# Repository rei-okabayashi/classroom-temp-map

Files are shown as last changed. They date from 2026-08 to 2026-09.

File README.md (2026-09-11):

# 教室の温度ムラ「見える化」

訓練校のチーム制作（自主活動・授業時間外）として、教室内の温度ムラをセンサーで可視化するプロジェクトです。
ESP32（無線通信ができる小型マイコンです。マイコンとは、プログラムで動く小さなコンピューターのことです）を使ったノード（教室に置く測定係の小さなコンピューターです。ESP32＋温湿度センサーのセットで、n1〜n4の4台があります）が、教室内の複数地点で温湿度を測ります。教壇のM5Stack（画面つきの小型マイコンです。教壇に置いて受信データを表示・記録します）に無線で集約したうえで、画面表示とSD記録を経てデータ分析まで行います。
メンバーは今回が初めてのチーム開発で、実際に手を動かして完成させる経験を積み、就活で語れる実績につなげることを目的にしています。
2026年8月17日のDay 0でチーム開発を開始し、9月4日に完成デモ、**9月11日（金）15:10から校内発表**を行います（普段の教室で、授業終了の5分後にそのまま始めます）。

## わかったこと（実測の結果）

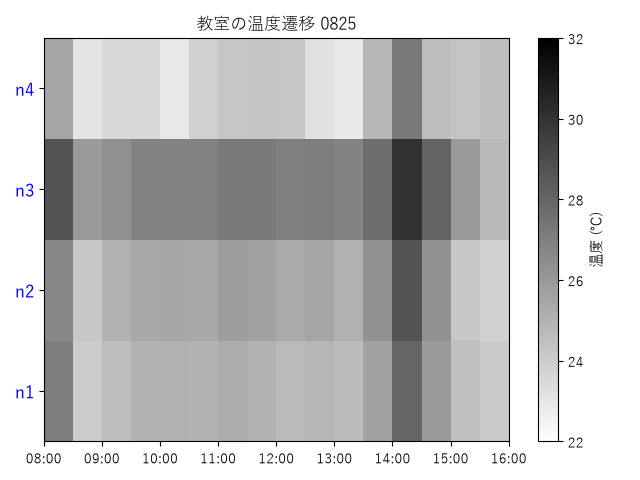
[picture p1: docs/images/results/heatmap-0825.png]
8/25の教室内温度のヒートマップ。横軸が時刻（8:00〜16:00）、縦軸が4つの設置地点、濃いほど高温


*8/25の実測例。縦軸のn1〜n4は下の「ノードと設置場所」の対応表のとおりで、n3が教卓付近です。発表当日に配ったA4資料に合わせて白黒に変換してあります（原図は分析担当がPythonのmatplotlibで作成）。*

2026年8月24日16:08〜8月28日15:47のあいだ、教室内の4地点で30秒ごとに測り続けた結果です。

- **同じ瞬間の最大の差は 4.3℃**（8/25 10:21。教卓 27.0℃ ↔ 廊下側前2 22.7℃）
- **4地点の温度差の中央値は 1.9℃**。9〜14時は約2℃、15〜16時は1.3〜1.4℃に縮みました
- 4台がそろって比較できた授業時間のうち、**約99%で教卓のほうが廊下側より暖かい**という、同じ向きの差が出ました
- エアコンを止めた休日に4台の値を突き合わせたところ、地点ごとの平均の幅は **0.18℃** でした。見たい差の10分の1以下だったので、**補正（校正）はかけず、生の値のまま**分析しています

「席によって暑い・寒いが違う」という体感が、数字として確かめられた形です。
集計とグラフの手順は [analysis/README.md](analysis/README.md)、スクリプトは [analysis/](analysis/) にあります。

## システム構成

図中のSHT31は、温度と湿度を測るセンサー部品の型番です。

```mermaid
flowchart LR
    n1["n1<br/>ESP32 + SHT31"]
    n2["n2<br/>ESP32 + SHT31"]
    n3["n3<br/>ESP32 + SHT31"]
    n4["n4<br/>ESP32 + SHT31"]
    gw["M5Stack Basic<br/>（教壇付近に常設予定）"]
    disp["画面表示 ＋ SD記録<br/>（LOG.CSV）"]
    analysis["SQLite / Python<br/>で分析"]
    demo["校内発表"]

    n1 -->|ESP-NOW 30秒ごと| gw
    n2 -->|ESP-NOW 30秒ごと| gw
    n3 -->|ESP-NOW 30秒ごと| gw
    n4 -->|ESP-NOW 30秒ごと| gw
    gw --> disp
    disp --> analysis
    analysis --> demo
```

## リポジトリ構成

リポジトリ（プロジェクト一式の保管場所です。フォルダごと、変更履歴つきで置いてあります）の全体は次のとおりです。

```
classroom-temp-map/
├── firmware/
│   ├── node-template/      # ノード側の雛形（コピーして使う。書き換えるのはconfig.hとreadSensor()のみ）
│   │   ├── node-template.ino
│   │   └── config.h
│   ├── nodes/               # 各メンバーが node-template をコピーして育てた実物（4台とも稼働ずみ）
│   │   ├── n1/n1.ino         # 【rei-okabayashi】
│   │   ├── n2/n2.ino         # 【M27Kyara】
│   │   ├── n3/n3.ino         # 【fukura-suzme】
│   │   └── n4/n4.ino         # 【mozu-sabo】
│   └── gateway/              # 集約側（M5Stack Basic）。表示とSD記録を担当
│       ├── gateway.ino
│       └── config.h
├── hardware/
│   └── case/                 # ノードを収める3Dプリント筐体（全高58.5mmの3段積み）
│       ├── node_case_v3.py   # 設計の元データ（build123d。寸法を変えて出力し直せます）
│       └── stl/              # 印刷用STL（shell_n1〜n4 ＋ box ＋ lid）
├── docs/
│   ├── data-contract.md      # ノード⇄集約の通信・データ形式の約束事
│   ├── setup-windows.md      # 開発環境セットアップ・ビルド・書き込み手順（Windows）
│   ├── first-boot-check.md   # 初回起動チェックとデータ回収の手順
│   ├── final-week.md         # 完成デモからの仕上げの段取り
│   └── presentation-outline.md  # 校内発表の構成案と想定問答
├── analysis/
│   ├── log_to_sqlite.py      # LOG.CSV→SQLite取り込み＋基本集計（標準ライブラリのみ）
│   ├── heatmap_temp.py       # 時間帯×地点のヒートマップ（pandas + matplotlib）
│   ├── data_analysispra.py   # 1地点ぶんの折れ線グラフ
│   ├── data_multibar.py      # 4地点をまとめた折れ線グラフ
│   ├── README.md             # 分析担当の作業手順
│   └── sample/LOG.CSV        # 動作確認用ダミーデータ
├── .github/
│   ├── ISSUE_TEMPLATE/task.md
│   └── pull_request_template.md
└── .gitignore
```

## 資料の読みかた

知りたいところだけ開けば大丈夫です。全部読む必要はありません。

| 知りたいこと | 読むもの |
|---|---|
| ノードと集約の通信・データ形式の取り決め | [docs/data-contract.md](docs/data-contract.md) |
| 開発環境の作り方・ビルド・書き込み（Windows） | [docs/setup-windows.md](docs/setup-windows.md) |
| 設置した機材の初回チェックとデータ回収 | [docs/first-boot-check.md](docs/first-boot-check.md) |
| 集計とグラフの手順 | [analysis/README.md](analysis/README.md) |
| 発表の構成と想定問答 | [docs/presentation-outline.md](docs/presentation-outline.md) |
| 完成デモから発表までの段取り | [docs/final-week.md](docs/final-week.md) |
| ノードのケース（3Dプリント） | [hardware/case/README.md](hardware/case/README.md) |
| 各ノードのコードの育て方 | [firmware/nodes/README.md](firmware/nodes/README.md) |

制作期間中に使っていた進め方の資料（Day 0の進行台本、放課後の時間割、Git素振り、初期タスク台帳、タスクカードの見かた、拡張バックログ、削る順序など）は、
**制作の終了にあわせて整理しました**。役目が終わった足場なので消しましたが、変更履歴には残っているのでいつでも取り出せます。
やったことの記録としては、Issue（#7〜#29 ほか）とPRの履歴のほうが実物に近いです。

## データ契約

ノードと、集約役のM5Stack（ゲートウェイとも呼びます。4台のノードからデータを受け取ってまとめる係です）の間の約束事は [docs/data-contract.md](docs/data-contract.md) に定義しています。要点だけ書くと：

- 30秒に1回、ESP-NOW（WiFiルーターなしでESP32どうしが直接データを飛ばせる無線のしくみです）を使って送信します。ユニキャスト（その場の全員に向かって叫ぶのではなく、宛先を1台決めて送る方式です）で送り、チャンネル（無線の通り道の番号です。トランシーバーの「チャンネルを合わせる」と同じ考え方です）は1に固定、暗号化はなしです。データの形式はJSON（ジェイソン。「項目名:値」をカンマで並べる、機械が読み間違えないためのデータの書き方です）を使います。送達確認がNGの場合は、1秒後に1回だけ再送します。
- ペイロード（1回の送信で運ぶデータの中身です）例：`{"v":1,"id":"n1","seq":123,"t":26.4,"h":55.2}`（読み下すと「契約の版は1。私はノードn1。起動してから123回目の送信。気温26.4℃、湿度55.2%」という内容です。読み取り失敗時は`t`/`h`の代わりに`"err":"sensor"`を送ります）。
- 集約側はSDカードの `LOG.CSV`（CSV＝カンマ区切りの表形式ファイルです。Excelやスプレッドシートでそのまま開けます）に、生値（生データ。センサーが返した値を補正せずそのまま記録したものです）のまま1行ごとフラッシュ（flush。書き込み待ちのデータをその場でSDカードに確定させることです。突然電源が切れても消えないようにします）で記録します（列：`recv_time,clock,node_id,seq,temp_c,hum_pct,status`）。追加の校正（キャリブレーション＝基準になる温度計と並べて測り、センサーごとのズレを調べること）は実施しません。SHT31が出荷時に校正済みのセンサーであるためです（理由は docs/presentation-outline.md の想定問答3）。画面表示も記録も分析も生値で統一していて、補正はどこにも掛けていません。

## チームの決めごと

ここにある決めごとは企画者が用意した叩き台です。Day 0で確認して確定し、9/4のKPT（ふりかえりの型です。Keep＝続けること・Problem＝困ったこと・Try＝次に試すこと、の3つで振り返ります）で見直します。

### Git運用

GitHub（書いたプログラムの変更履歴を記録・共有できるWebサービスです）上でチーム開発を進めます。

- Git運用の流れは「ブランチを切る → PRを出す → 企画者レビュー → マージ」です。ブランチ（feature branch）とは、本体（main）に影響を与えずに作業するための、枝分かれした作業用コピーです。PR（Pull Request）とは、「この変更を本体に取り込んでください」という提案で、チームの誰かが確認してから取り込みます。マージとは、提案された変更を本体に取り込むことです。
- `main` への直接push（プッシュ：自分のPCでの記録をGitHub側に送って反映することです）は禁止です
- ツールはgitコマンドとVSCodeを使います（GitHub Desktopは使いません）

### AIルール

1. 共通テンプレートを使います（各自のノードは `firmware/node-template/` をコピーして始めます）
2. データ形式の契約を守ります（`docs/data-contract.md` のフィールドを勝手に増やしません。変えたいときはチームで合意してから版を上げます）
3. 説明できないコードはマージしません（AIに書かせた部分も含めて、PRの説明欄に自分の言葉で書きます）
4. AI利用箇所を記録します（日々の記録はPR説明欄に書き、発表とりまとめ担当が「AI活用の記録」節の表に転記します。企画者は内容をレビューで確認します）

使いどころの目安は次のとおりです。エラーメッセージの解読・コードの意味の説明・文章や表の下書きには積極的に使ってOKです。コードを丸ごと生成させて、自分で説明できないまま持ち込むのはNGです（ルール3のとおり）。

### 週次リズム

- 月曜: 週次キックオフ15分（今週の各自のタスクカード＝Issue（やることを1件ずつカードにしたものです）を確認します）
- 毎日: Discordに2行報告します（きょうやった／困ってる）。書くだけでOKです。返信は必須にしません
- 金曜: 中間デモ（8/21・8/28）です。進捗の判定はこの場でだけ行います。9/4(金)は完成デモ＋ふりかえり（KPT）です
- 詰まったら24時間以内に申告してください→企画者と30分ペア作業します。遅れは責めません（タスクの切り方が悪かったとみなして分解し直します）
- 時間の上限は週5〜8hです。上限は超えません（作業量は役割ごとに波がありますが、上限と見える化で揃えます）
- 完成が危うくなったら、あらかじめ決めた順に規模を削ります（削る順序は、着手前に決めて文書化しておきました）

## 役割分担表

| 役割 | 担当 | 補足 |
|---|---|---|
| 企画・全体とりまとめ | 【rei-okabayashi】 | テンプレート整備・レビューを行います。**他メンバーの**ノード実装と発表スライド本体には手を出しません（自分のノード1台は担当します） |
| ノード担当（n1〜n4） | 【rei-okabayashi】【M27Kyara】【fukura-suzme】【mozu-sabo】 | 企画者を含めて1人1台です。センサー実装・設置・動作確認を行います |
| 集約表示オーナー | 【fukura-suzme】 | M5Stack側の画面表示・SD記録を担当します。担当者はノード1台と兼務します（4名全員がノード1台ずつ担当するためです）。M5Stackは企画者の個人所有物のため、譲渡の対象外です |
| データ分析 | 【mozu-sabo】 | 訓練校で学んだSQLite（ファイル1つで使える小さなデータベースです）を活用します |
| 発表とりまとめ | 【M27Kyara】 | 校内発表用スライドを作成します |
| 筐体 | 【rei-okabayashi】 | ノードのケース化などを行います。基本は企画者が担当しますが、やってみたい人がいればその人が正式な担当になります（他の役割と同格です） |

※ 1人が複数の役割を兼ねることがあります。担当欄はGitHubのユーザー名で記入します（公開リポジトリのため本名は書きません）。

## ノードと設置場所

| ノードID | 設置場所 | 担当 |
|---|---|---|
| n1 | 窓側（後ろ寄り） | 【rei-okabayashi】 |
| n2 | 窓側（前寄り） | 【M27Kyara】 |
| n3 | 教卓付近 | 【fukura-suzme】 |
| n4 | 廊下側（前寄り） | 【mozu-sabo】 |

設置場所は「窓側」「廊下側」「教卓付近」のような役割ベースの言い方にしています。

## 機材と費用

### 機材一覧

使用機材の一覧です。担当作業で「この部品の特性（ピン配置・仕様・使い方）を知りたい」となったら、**資料列のリンク**を開いてください。アイテムごとに、いちばん役立つ資料を1つだけ厳選して貼ってあります。参考単価は秋月電子への発注時（2026-08-01）のものです。

| 機材 | 数量 | 参考単価 | このプロジェクトでの役割 | 資料（各1つ厳選） |
|---|---|---|---|---|
| ESP32-DevKitC-32E ESP32-WROOM-32E開発ボード 4MB（秋月 115673） | 4（発注3＋追加1） | ¥1,800 | ノードn1〜n4の本体です（1人1台）。PCからUSBで書き込み、ESP-NOWで測定値を送信します | [ESP32-WROOM-32Eデータシート（PDF・英語）](https://akizukidenshi.com/goodsaffix/esp32-wroom-32e_esp32-wroom-32ue_datasheet_en.pdf) |
| SHT31使用 高精度温湿度センサーモジュールキット（秋月 112125） | 4 | ¥950 | 温湿度の測定部です。I2C（少ない配線でマイコンと部品がやり取りする通信方式です）でESP32につなぎます。配線は3V3・GND・SDA(21)・SCL(22)の4本だけです | [組立・使用説明書（PDF・日本語）](https://akizukidenshi.com/goodsaffix/AE-SHT3x_manu_v1.0.pdf) |
| USBケーブル USB2.0 Aオス-マイクロBオス 1.5m（秋月 107607） | 4 | ¥170 | ノードの書き込み・給電用です（DevKitCの差し込み口はmicro-Bです） | [商品ページ](https://akizukidenshi.com/catalog/g/g107607/) |
| スイッチングACアダプター Type-Aメス 5V2A 横出し（秋月 114934） | 5 | ¥580 | 設置後の常時給電用です（ノード4台＋M5Stack1台分）。上のUSBケーブルをこれに挿してコンセントから電源をとります | [商品ページ](https://akizukidenshi.com/catalog/g/g114934/) |
| コネクター付ケーブル 20cm 40P メスメス（秋月 115868） | 1 | ¥200 | ESP32とSHT31をつなぐ配線材です。40本つながったリボン状なので、1台あたり4本ずつ裂いて使います | [商品ページ](https://akizukidenshi.com/catalog/g/g115868/) |
| USBケーブル USB2.0 TypeAオス⇔TypeCオス 1.5m（秋月 113563） | 1 | ¥130 | M5Stackの書き込み・給電用です（Basicの差し込み口はUSB-Cです） | [商品ページ](https://akizukidenshi.com/catalog/g/g113563/) |
| M5Stack Basic（初期型） | 1 | —（企画者私物） | 集約ゲートウェイです。4台のノードからESP-NOWで受信し、画面表示とSDカードへの記録を行います | [公式ドキュメント（日本語）](https://docs.m5stack.com/ja/core/basic) |
| microSDカード（LAZOS 16GB Class10） | 1 | 約¥1,000 | `LOG.CSV` の記録先です。M5StackのTFカードスロットに挿して使います | [メーカー製品ページ（L-B16MSD10-U1）](https://lazos-life.com/l-b16msd10-u1/) |

資料を読むときのヒント：

- ESP32のデータシートは英語ですが、全部読む必要はありません。ピンの役割は「Pin Definitions」、電圧・電流の上限は「Electrical Characteristics」の節だけ見れば十分です。
- SHT31の説明書は日本語で、組み立て（同梱ピンヘッダーのはんだ付け）・配線例・I2Cアドレスの切り替え・Arduinoのサンプルコードまで載っています。ノード担当が最初に読む資料はこれです（I2Cアドレスは基板そのままで `0x45`。`firmware/node-template/config.h` の設定と対応しています）。
- M5Stackのドキュメントにはバージョン違い（v2.6／v2.7）のページもありますが、今回の機体は初期型なので無印「Basic」のページを見てください。
- 秋月の商品ページはURLが `https://akizukidenshi.com/catalog/g/g<6桁コード>/` の形式です。表の「秋月 6桁」の番号からたどれます（リンク切れのときもこの形で復元できます）。

### 費用

- 秋月電子への発注分（2026-08-01）：¥13,110（上の表の単価×数量の合計。ただしESP32は3台分）
- ESP32-DevKitC-32E 追加1台（4台目）：¥1,800（参考単価）
- microSDカード（LAZOS 16GB Class10）：約¥1,000
- M5Stack Basicは企画者の私物のため、費用には計上しません
- 機材は企画者が用意します。プロジェクト終了後（9月の発表・運用終了後）に譲渡（センサーノードのみ。集約のM5Stackは対象外です）を希望するメンバーは、実費¥3,500/台です

## AI活用の記録

チームルール4（AI利用箇所をREADMEに明記します）の実践場所です。

記録は「AIを使った／使っていない」の二択にはしません。**「AIがやったこと」と「人間が判断・検証したこと」を分けて**、下の表の形式で書きます。AIに書かせること自体はルール違反ではありません——ルール3のとおり、自分の言葉で説明できることがマージの条件です。

| どこで | AIがやったこと | 人間が判断・検証したこと |
|---|---|---|
| 共通テンプレート（`firmware/node-template/`・`firmware/gateway/`） | コードの下書きを生成（Claude） | 企画者が仕様（データ契約）を決めてレビュー・修正し、コンパイルと実機の送受信で検証 |
| データ契約のドラフト（`docs/data-contract.md`） | 文書の下書きを生成（Claude） | チームで内容を確認し、企画者の承認でv1として確定 |
| このREADMEと `docs/` の各手順書 | 文章の下書きを生成（Claude） | 企画者が内容をレビュー・修正して確定 |
| #1 — ドキュメント（学校PC対応） | IDEフリーズ原因の切り分け案とプロキシ設定手順の下書き作成 | 実機での手順動作確認・最終文面の採択 |
| #2 — ドキュメント（トラブルシューティング） | clone先フォルダ既存エラーへの対処文の下書き作成 | 文面内容の確認と推敲 |
| #4 — ドキュメント（自己紹介） | 自己紹介文の自動生成 | 生成文の内容確認・必要な修正 |
| #5 — ドキュメント（Git演習手順） | 演習手順ドラフトを生成（実測値を踏まえた文面） | 実機での検証を経て採択 |
| #6 — ドキュメント（git-primer） | トラブル洗い出しと修正案（複数ファイル）の生成 | 提案の検証および採択 |
| #34 — ドキュメント（README 機材欄） | 機材説明文の作成（表・説明文案） | 内容の確認・必要箇所の修正 |
| #38 — ドキュメント（firmware/nodes README） | README 下書きの生成 | 文面の確認 |
| #40 — ドキュメント（first-boot-check） | 文章の校正・ブラッシュアップ支援 | 元原稿との差分確認・最終調整（原稿は人作成） |
| #41 — ハードウェア（3Dプリント設計） | ハードウェア説明メモ／設計アドバイスの生成 | メモの採否・設計の現物合わせ判断 |
| #43 — プログラム（折れ線グラフ） | 実装でのメソッド／関数選定に関する相談と提案 | 提案の採用箇所をコードに反映しコメントで記録 |
| #47 — CI/CD（GitHub Actions） | コンパイル自動チェック用ワークフロー案の作成・問題指摘 | CI案は未採用、スケッチ名の修正は#58で対応 |
| #50 — 設定（CODEOWNERS） | CODEOWNERS案作成・存在しないアカウント等の検出支援 | 未採用 |
| #51 — プログラム（M5Stack表示） | コンパイルエラーメッセージ解析・描画座標計算の提案 | エラー原因の特定とコード調整・動作確認 |
| #52 — ドキュメント（方針反映） | 複数ファイルの書き換え下書き（方針反映）を生成 | 人による突合せ・修正のうえ採択 |
| #53 — ドキュメント（README 役割表） | 役割表・設置場所の差替下書きを生成 | 確定値との照合・修正 |
| #54 — プログラム（折れ線グラフ一括出力） | グラフ作成プログラムの実装補助・アドバイス | 実装へ取り込み・動作確認 |
| #55 — ドキュメント（final-week） | 発表日確定に伴う資料下書き・日付更新の生成（Claude Code） | 関係者による突合せ・修正 |
| #57 — プログラム（集約画面UI） | ラベル表示・描画修正コードの全体生成（Claude Code） | 表示調整・実機確認を経てマージ済み |
| #58 — ファームウェア（スケッチ名修正） | 問題指摘・リネーム作業と説明文の生成 | 内容検証・リネーム適用 |
| #59 — ドキュメント（想定問答） | 想定問答への追記下書き生成（Claude Code） | 文意確認・採用（必要箇所を修正） |
| #60 — analysis（ヒートマップ） | 自分のコードをAIに見てもらい、書き方のわからないところやブラッシュアップしてほしい所を助けてもらい、結果的に大半をAIの提案によるコードを採用 | データベースの値と描画の突合せ・動作確認 |
| #62 — docs（想定問答・プロキシ例） | Codexで既存の集計定義と説明を照合し、数値の意味の補足およびプロキシ設定の例示化を実施 | 文言確認・採択 |
- 各メンバーが自分のノード（`firmware/nodes/n1`〜`n4`）でAIを使った場合は、そのPRの説明欄（`AIを使った箇所`）に個別に記録します。ルール3のとおり、AIに書かせた部分も自分の言葉で説明できることが前提です。
- PR説明欄の記録は、中間デモ（8/21・8/28）とKPT（9/4）のタイミングで、**発表とりまとめ担当が上の表に転記します**（企画者は内容をレビューで確認します）。記録の散逸を防ぐと同時に、発表スライドの「AIとの付き合い方」の材料づくりを兼ねます。

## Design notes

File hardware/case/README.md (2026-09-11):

# ノードケース（3Dプリント）

ESP32-DevKitC-32E（秋月 115673）と SHT31温湿度センサー（秋月 112125）を収める、
教室常設用のケースです。Bambu Lab A1 mini での印刷を前提にしています。
ここにあるのは2026年8月30日時点の版（v3）で、4台ともこのケースに入れて9月1日から教室に設置しました。

## 設計のいちばん大事な話 — センサーとESP32を縦に離す

ESP32は動作中に自分が発熱します（無線送信と電源レギュレータの熱です）。
温度センサーを同じ空間に閉じ込めると、**教室の気温ではなく「箱の中の温度」を測ってしまい、
実際より高い値**が出ます。教室の温度ムラ（実測で数℃）を測るプロジェクトでは致命的です。

そこでこのケースは、**下からセンサー室 → 空気の断絶帯 → ESP32室** の縦積みにしています。

```
        ┌──────────┐
  +48.8 │   lid    │  フタ。ESP32を上から押さえ、CPU直上に排熱の煙突とハニカム孔
        ├──────────┤
  +24.5 │   box    │  ESP32室。基板を棚に載せる。USB窓・配線穴・排気スリット
        ├──────────┤
        │  = 空気 = │  断絶帯 5.0mm（ここで熱がセンサーへ伝わりにくくなる）
        │          │
      0 │  shell   │  外殻。最下部がセンサークレードル（SHT31を上から落とし込む）
        └──────────┘   背面に磁石ポケット2個。底面の前バンドにノードIDを刻印
```

全高58.5mm、設置面は 60.3 × 33.5mm。**背面（机側）はshellからlidまで1枚の平面**なので、
磁石で壁やスチール面にぴったり付きます。

## パーツ構成

| ファイル | 中身 |
|---|---|
| `stl/node_case_v3_shell_n1.stl` 〜 `_n4.stl` | 外殻＋センサークレードル。**n1〜n4で違うのは底面の刻印だけ**です（設置後にどの子機か見分けるため） |
| `stl/node_case_v3_box.stl` | ESP32室。4台とも共通 |
| `stl/node_case_v3_lid.stl` | フタ。4台とも共通 |
| `node_case_v3.py` | 設計の元データ（後述） |

1台分 ＝ shell 1個 ＋ box 1個 ＋ lid 1個。4台なら shell を n1〜n4 で1個ずつ、box と lid を4個ずつ。

## 部品以外に必要なもの

- **ネオジム磁石 φ13 × 厚2.4mm × 2個／台**（ダイソーの13mmタイプを実測した寸法でポケットを作っています）。
  shell背面のポケットに押し込みます。2個の縁を25.6mm離してあるのは、磁石どうしが引き寄せ合って
  設置しづらくなるのを避けるためです。SHT31への磁気の影響は調べたうえで無しと判断しています。
- ジャンパー線（メスメス4本。3V3・GND・SDA21・SCL22）

## 印刷

1. Bambu Studio に STL をドラッグ＆ドロップ
2. フィラメント: **PLA**。
   ただし **PLA Matte は層間の強度が PLA Basic の43%しかありません**（メーカーTDSの実測値）。
   スナップのツメなど細い部分が折れやすいので、Matteを使うなら扱いを丁寧に
3. 向き: **3部品ともエクスポートされたそのままの向き**で置けば、サポートは要りません
4. 最初は1台分だけ刷って実物で確かめてから、残り3台を刷ってください

### 寸法を変えたいとき

`node_case_v3.py` の先頭にパラメータがまとまっています（壁厚 `WALL`、外形 `FOOT_X`/`FOOT_Y`、
空気断絶帯 `GAP`、磁石 `MAGNET_D`/`MAGNET_T`、USB窓 `USB_SLOT_W` など）。
値を変えて実行すればSTLが出し直されます。

このファイルは [build123d](https://github.com/gumyr/build123d)（Pythonで形状を書くCAD）で動きます。

```
pip install build123d
python node_case_v3.py
```

実行すると `node_case_v3_box.stl` / `_lid.stl` / `_shell_n1`〜`_n4.stl` が同じフォルダに出力されます。

## 組み立て

1. **SHT31のピンヘッダは基板の裏側（部品がない面）から下向きに**はんだ付けします
2. ジャンパー線4本でESP32（3V3・GND・21・22）とSHT31（+V・GND・SDA・SCL）をつなぎ、
   **先にPCにつないで動作確認**（[docs/first-boot-check.md](../../docs/first-boot-check.md) のA章）してからケースに入れます
3. **SHT31をshellのクレードルへ**：**タブ（センサー素子が載っている出っぱり）を先に差し込んでから、
   後端を落とす**順番で入れます。先端のツメが基板の浮き上がりを押さえます
4. **ESP32をboxへ**：USBコネクタを右壁（X+）の窓に合わせて、基板を棚に載せます。
   ジャンパー線は基板の下の空間を通し、配線穴から下（shell側）へ回します
5. **boxをshellに載せる**：パラペット（shell上部の立ち上がり）の内側に差し込むと、
   ビードが受け溝にはまってカチッと止まります
6. **lidをかぶせる**：短辺（X±）のスカート脚がboxの壁をつかみます。書き込み直し（BOOTボタン）のときは外します
7. **磁石を2個**、shell背面のポケットに押し込んで設置

## この設計に至るまで（初回印刷でわかったこと）

8月30日の午前にフル1セットを試し刷りし、その実物を見て午後に直しました。
直した内容は `node_case_v3.py` の冒頭コメントに全部残してあります。主なものは：

| 見つかった問題 | 直し方 |
|---|---|
| センサー基板が浮き上がる | 先端にツメ（トンネル状の押さえ）を新設。両側のナブを太くする案は、通過隙間12.7mm＜基板幅14.0mmで**挿入できなくなる**ため不採用 |
| boxとshellが固定されない | 押し込んで嵌るスナップを新設（ギャップ0.5mmを跨いで0.30mm食い込む2段ビード） |
| ESP32の熱がこもる | lidの押さえパッドを煙突にしてCPU直上を貫通、プレートにハニカム孔、box壁の排気スリットを下へ延長 |
| 磁石どうしが引き寄せ合って設置できない | 2個を離して独立したポケットに（縁間25.6mm） |
| ESP32の赤LEDが眩しい | ハニカム孔をCPU側（X-）だけに限定し、LED側は無孔の目隠しに |
| 横の出っぱりが邪魔で壁に付き切らない | 長辺（Y±）を本体と面一化。lidのY側スカートを廃止し、係合を短辺（X±）へ移設 |
| 外壁と内壁が細くて不安定 | 薄壁2枚が非接合で並んでいた箇所を、段付きキャビティで一体の2.5〜3.7mm壁に統合 |

その前段では、嵌合部だけを切り出したテスト用の小片（クーポン）を刷って、
スナップの食い込みと、この設定で形が出る最小の寸法を確かめています。

## 設置時の注意

- 直射日光の当たる場所は避ける（日射でセンサーが数℃高く出ます。窓際なら日陰側に）
- エアコンの吹き出し直下も避ける（気流の温度を測ってしまいます）
- ESP32のアンテナ（基板端の模様部分）に金属を密着させない。ケースのPLA樹脂自体は電波をほぼ通すので問題ありません

## ケースの影響について

このケースが測定値を持ち上げていないか、**ケースあり／なしを並べて比べる測定はしていません**。
4台とも同じケースに入っているので、持ち上がりがあれば4台に同じだけ乗り、
このプロジェクトが見たい「地点どうしの差」には影響しない、という整理です。
絶対値の底上げがあるかどうかは未測定です（[docs/presentation-outline.md](../../docs/presentation-outline.md) の想定問答3）。

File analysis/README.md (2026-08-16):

# analysis — 運用データの分析（データ分析担当の作業場所）

SDカードにたまった実測データを読み込んで、「いつ・どこが暑いか」を数字で出す場所です。
このプロジェクトの成果物（発表で見せるもの）は、ここから作ります。

---

## 0. 準備：Pythonを入れる（最初に1回だけ）

`log_to_sqlite.py` は **Python** というプログラムで動きます。入っていないPCでは動かないので、先に入れてください。

1. [https://www.python.org/downloads/windows/](https://www.python.org/downloads/windows/) を開き、Windows installer (64-bit) をダウンロードします。
2. ダウンロードした `.exe` を実行します。**最初の画面で「Add python.exe to PATH」のチェックを必ず入れてください**（ここを忘れると、次の手順で `python` と打っても認識されません）。
3. 「Install Now」を押します。
4. **開いていたターミナルはいったん閉じて、開き直します**（開きっぱなしの画面には設定の変更が反映されません）。
5. ターミナルで `python --version` と入力してEnterを押し、`Python 3.x.x` のように表示されれば準備完了です。

> **うまくいかないとき**
> - Microsoft Storeの画面が開いてしまう → 手順2の「Add python.exe to PATH」のチェックが入っていません。インストーラをもう一度実行して入れ直してください。
> - それでも認識されない → PCを再起動してから、もう一度 `python --version` を試してください。
> - どうしても入らない → 企画者に連絡してください。**Excelでも同じ集計はできます**（下の「Pythonが使えないとき」を参照）。

**追加のライブラリは要りません。** `log_to_sqlite.py` はPythonに最初から入っている機能だけで動きます。

---

## 1. まずはサンプルで動かしてみる（実データが無くてもできます）

実測データが集まるのは8/26以降です。それまでに、**ダミーデータで一度動かしておく**と本番で慌てません。

1. VSCodeでこのリポジトリ（`classroom-temp-map` フォルダ）を開きます。
2. メニューの `ターミナル`（Terminal）→ `新しいターミナル`（New Terminal）を開きます。
3. `analysis` フォルダへ移動します。

   ```
   cd analysis
   ```

4. サンプルデータで実行します。

   ```
   python log_to_sqlite.py sample/LOG.CSV
   ```

うまくいけば、ノード別のまとめと「時間帯 × ノードの平均気温」の表が画面に出ます。
**この表の一番右の「最大差」の列が、私たちが測ろうとしている「温度ムラ」そのものです。**

---

## 2. 本番：実測データで動かす

1. **回収したLOG.CSVを受け取ります。** 金曜のデータ回収のあと、回収した人が Discord の進捗報告チャンネルに `LOG.CSV` を添付します。それをダウンロードして、この `analysis` フォルダに置いてください（回収の手順は [docs/first-boot-check.md](../docs/first-boot-check.md) のC章）。
2. `analysis` フォルダにいることを確認して、実行します。

   ```
   python log_to_sqlite.py LOG.CSV
   ```

3. 画面に出た表を保存します。スクリーンショットでもよいですし、次のようにファイルへ書き出すこともできます。

   ```
   python log_to_sqlite.py LOG.CSV > result.txt
   ```

このコマンドは `LOG.CSV` を読み込み、SQLiteのデータベースファイル `onmura.db` を作ります（`onmura` は「温度ムラ」をローマ字にした、このプロジェクトの略称です）。

- `onmura.db`（SQLite。ファイル1つで使える小さなデータベースです。訓練校で学習済み）が作られ、ノード（教室に置く測定係の小さなコンピューターです）別サマリと「時間帯×ノードの平均気温」クロス表が表示されます
- **最大差の列が「温度ムラ」そのものです** — 発表の根拠データはここから作ります
- 訓練で習ったSQLiteの実践場所です。`sqlite3 onmura.db`（作られたデータベースを開いて、自分で集計を試すためのコマンドです）で開いて自由に集計してかまいません

時刻未設定（clock=unset）の行とセンサーエラー行は自動で除外されます（`--include-unset` で含められます）。
また、同じデータが2回記録されていた分（電波が届かず再送されたとき）も自動で1件にまとめられます。

---

## 3. どこまでやれば「できた」か

| 段階 | 中身 | 判定 |
|---|---|---|
| **最低限** | 上のクロス表と「最大差」の列＋グラフ1枚 | **これで発表に使えます** |
| 余裕があれば | 日別・曜日別の集計を足す | 拡張 |
| さらに | 設置場所ラベル（READMEのn1〜n4対応表）と結合して「窓際 vs 廊下側」で語る | 拡張 |

グラフを何で作るか（表計算ソフトか、Pythonのグラフ機能か）は、**1週目のうちに企画者と相談して決めます**。
どちらでも構いませんが、Pythonのグラフ機能（matplotlib）を使う場合は `pip install matplotlib` の追加インストールが必要になるので、早めに決めておくと安心です。

> 発表のグラフでは、`n1`〜`n4` という名前を「窓際」「廊下側」のような言い方に置き換えます（公開リポジトリなので、学校や教室が特定される表現を避けるためです）。集計をやり直す必要はなく、見出しの言い換えだけです。

---

## 4. Pythonが使えないとき（Excel・スプレッドシートで同じことをする）

`LOG.CSV` はただのCSVなので、ExcelやGoogleスプレッドシートで開いてピボットテーブルを作れば、同じクロス表が作れます。
ただし、**スクリプトが自動でやっている「除外」を手でやる必要があります。** ここを飛ばすと、気づかないまま平均がおかしくなります。

1. `clock` 列が `set` 以外（`unset`）の行を消します（停電などで時計が未設定だった間の行で、時刻が当てになりません）
2. `status` 列が `ok` 以外（`sensor_err`）の行を消します（気温が空欄の行です）
3. 同じ `node_id` で `seq` が直前の行と同じものがあれば、片方を消します（再送で二重に記録された分です）
4. `recv_time` の列を、日付・時刻として認識させます（列を選んで「セルの書式設定」から変更します）
5. ピボットテーブルで `recv_time` を右クリック →「グループ化」→ **「時」だけにチェック**を入れます

手数が多いので、Excelに切り替えると決めたときは企画者に声をかけてください。**除外まで済ませたシートを一度作って渡します。**

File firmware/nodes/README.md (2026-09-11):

# firmware/nodes/ — 各自のノードのコード置き場

このフォルダには、**自分が担当するノードのコード**を置きます。`n1/`〜`n4/` の各フォルダが、そのまま担当者1人分です。
どの番号が誰の担当かは、リポジトリのトップの [README.md](../../README.md) の構成図と役割分担表を見てください。

## 置くファイルは2つだけです

`firmware/node-template/` の中身をコピーして、自分の番号に合わせた名前で置きます。

- `nX.ino` … `node-template.ino` をコピーして名前を変えたもの
- `config.h` … そのままコピーして、下の2か所だけ書き換えたもの

**フォルダ名と `.ino` のファイル名は必ずそろえてください**（`n2/` なら `n2.ino`）。
名前が違うと Arduino IDE でスケッチ（プログラムのひとまとまり）を開けません。

## 書き換えるのは2か所だけです

`config.h` の中の次の2つだけを変えます。ほかは変えません。

- `NODE_ID` … 自分の番号（`"n2"` のように書きます）
- `GATEWAY_MAC` … 集約M5StackのMACアドレス（機器1台ごとに付いている固有の番号です）

## GitHubに上げるときの注意

**`GATEWAY_MAC` は、雛形の `{0x00, 0x00, 0x00, 0x00, 0x00, 0x00}` に戻してからコミットしてください。**
教室に置いてある機材のアドレスを、誰でも見られる場所に残さないためです。

そのため、**ここに置いてあるコードは、そのままでは動きません**。
実機に書き込むときは、各自が自分の手元でMACアドレスを本当の値に直してから書き込みます。
MACアドレスは、gateway（M5Stack）を起動したときに画面とシリアルモニタに `MAC: 24:0A:C4:12:34:56` の形で出ます。
`config.h` に書くときは、①コロン `:` をカンマ `,` に変える ②2文字ずつの前に `0x` を付ける ③全体を `{ }` で囲む、の3つだけです。

```
【画面に出る表示】  MAC: 24:0A:C4:12:34:56
【config.h に書く形】static const uint8_t GATEWAY_MAC[6] = {0x24, 0x0A, 0xC4, 0x12, 0x34, 0x56};
```

書けたら数えてください。**`0x` が6個、カンマが5個**あれば正しい形です（上の値は書き方の例です）。

## `.gitkeep` というファイルについて

各フォルダに入っている `.gitkeep` は、**中身が空のフォルダをGitで扱えるようにするためだけ**に置いてある、何も書かれていないファイルです。
Gitは「空のフォルダ」を記録できないので、置き場所を先に作っておくために使っています。

自分のコードを置いたあとは、消してもかまいません（残っていても害はありません）。

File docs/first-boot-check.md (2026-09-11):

# 実機チェックシート — 初回動作確認と日常運用

**対象者**：初回の動作確認（A章）は企画者、8/17週にA章の該当部分を自分のノード（ノードとは、教室に置く測定係の小さなコンピューターです。ESP32というマイコン（＝プログラムで動く小さなコンピューター）と温湿度センサーがセットになっていて、n1〜n4の4台があります）で確認するのはノード担当全員、常設期間中の日常チェック・データ回収（B・C章）は当番になった全員です。
**使い方**：機器が届いたらA章を1台ずつ確認し、8/26以降は教室で最初に画面を見た人がB章の3点を毎日確認します。金曜はC章でデータを回収し、停電のあとはD章、開発中のテスト送信はE章を参照してください。

書き込みとシリアルモニタ（マイコンが出すメッセージをPCの画面で見るための窓です）の基本操作（Arduino IDEでの書き込み手順・シリアルモニタの開き方）は `docs/setup-windows.md` の7章にあるので、ここでは繰り返しません。

---

## A. 初回の動作確認（機器が届いたら1台ずつ）

### A-1. 集約（M5Stack）単体

集約は、4台のノードからデータを受け取ってまとめる係のM5Stackです（M5Stackは画面つきの小型マイコンで、教壇に置いて受信データを表示・記録します）。

1. `firmware/gateway/gateway.ino` を書き込みます（書き込み手順は setup-windows.md 7章「集約担当のみ：M5Stackへの書き込み確認」を参照してください）。
2. シリアルモニタ（115200 baud。baud＝通信速度の設定値です。PC側とボード側で同じ値に合わせます）に次の出力が出ることを確認します。

   ```
   === onmura gateway ===
   MAC: xx:xx:xx:xx:xx:xx
   ```

   （`onmura` は「温度ムラ」をローマ字にした、このプロジェクトの略称です。画面の表示やファイル名など、日本語が使えない場所で使っています。）

3. M5Stackの画面下部にも同じMACアドレス（機器1台ごとに工場出荷時から付いている固有の番号で、機器の住所のようなものです）が表示されることを確認します（画面はラベルが `MAC` 、シリアルは `MAC:` と表記が少し違いますが、アドレスの値は同じです）。SDカードを挿していなければ、画面右下は赤い「SD NG」です。
4. 画面上部に赤字で「JIKOKU MISETTEI  (serial: TIME ...)」という時刻未設定の警告が出ますが、まだTIMEコマンドを送っていないこの時点では**正常**です（A-6で設定します）。

**完了チェック**：シリアルと画面のMACアドレスが一致していればA-1は完了です。このMACアドレスは、あとで各ノードの `config.h` に転記する値なのでメモしておいてください。

### A-2. SDカード

1. FAT32でフォーマットした16GB以下のmicroSDカードを挿し、M5Stackを再起動します（フォーマットは、カードをPCに挿してエクスプローラーでドライブを右クリック →「フォーマット」→ ファイルシステムに **FAT32** を選び、クイックフォーマットで実行します。中身は全部消えます）。
2. 画面右下が緑の「SD OK」に変わることを確認します。

**うまくいかないとき**：「SD NG」のままなら、カードの抜き差し・再フォーマットを試してください。

### A-3. ノード単体

> **どのファイルを触るかは、時期で変わります。**
> - **企画者が最初に1台だけ動作を見るとき**（機器が届いた直後）は、まだ各自のフォルダが無いので `firmware/node-template/` をそのまま使います。
> - **メンバーが自分のノードを確認するとき**（8/17週以降）は、初期タスク#6〜#9で作った**自分のフォルダ** `firmware/nodes/n1/`（n2〜n4も同様）を使います。**共通の雛形である `node-template` は書き換えません**（4人が同じファイルを書き換えると、あとで必ずぶつかります）。
>
> 以下では、自分のフォルダを `firmware/nodes/n1/` として書きます。企画者の初回確認では `firmware/node-template/` に読み替えてください。

1. `firmware/nodes/n1/config.h` の `NODE_ID` を自分のノードID（`"n1"`〜`"n4"`）に書き換えます。
2. `firmware/nodes/n1/n1.ino` を書き込みます。
3. シリアルモニタに次の出力が出ることを確認します。

   ```
   === onmura node ===
   NODE_ID=n1  schema v1
   my MAC: xx:xx:xx:xx:xx:xx
   ```

4. `GATEWAY_MAC` をまだ `config.h` に転記していない段階では、続けて次の警告が出ますが、これは**正常に動いている証拠**です。

   ```
   !!! 警告: GATEWAY_MAC が未設定(全て0x00)です。
   !!! M5Stackの画面に出るMACを config.h に転記してください。
   ```

**完了チェック**：`=== onmura node ===` と `NODE_ID` 行、`my MAC:` 行が出ていればA-3は完了です。

### A-4. ESP-NOW疎通

ESP-NOW（WiFiルーターなしでESP32どうしが直接データを飛ばせる無線のしくみです）が正しくつながっているかを確認します。

1. A-1で確認した集約のMACアドレスを `config.h` の `GATEWAY_MAC` に1バイトずつ転記し、再書き込みします。
2. 30秒ごとにシリアルモニタへ「send ok : {...}」の行が出て、M5Stackの画面にそのノードの温湿度が表示されることを確認します。

**うまくいかないときの切り分け順（この順で確認してください）**：
① `firmware/node-template/config.h` と `firmware/gateway/config.h` の `WIFI_CHANNEL` が両方とも `1` になっているか確認します（送受で一致している必要があります）。
② `GATEWAY_MAC` の転記を1バイトずつ再確認します（コピーミスがいちばん多い原因です）。
③ シリアルに「add_peer failed. config.h の GATEWAY_MAC を確認してください」が出る場合は、転記の書式（`0x??` 形式・カンマ区切り）を確認します。
④ ①〜③で解決しない場合は、2台の距離を近づける・給電（USBポートやケーブル）を変えて再試行してください。

### A-5. SD記録

1. A-4の状態で数分間受信させます。
2. M5Stackの電源を切り、SDカードをPCで開きます。
3. `LOG.CSV`（カンマ区切りの表形式ファイルで、Excelやスプレッドシートでそのまま開けます）にヘッダ行と受信行が残っていることを確認します。これは1行ごとにフラッシュ（書き込み待ちのデータをその場でSDカードに確定させることです。突然電源が切れても消えないようにするしくみです）されているかどうかの確認です。

**完了チェック**：ヘッダ行 `recv_time,clock,node_id,seq,temp_c,hum_pct,status` の下に、受信した分だけ行が並んでいればA-5は完了です（`seq` は通し番号です。送信のたびに1ずつ増え、番号が飛んでいたら途中のデータが消えたと分かります）。

### A-6. 時刻設定

M5Stack本体（Basic/Gray）には、電源オフ時に時刻を保持するハードウェア（RTC）が内蔵されていません。そのため、起動後にPCからシリアル通信を介して現在時刻を送信し、内部時刻を設定する必要があります。

**注意点**
- 時刻の揮発性: 設定した時刻情報は、M5Stackの電源を落とすと消去されます。
- 電源切り替え時のリセット防止: 時刻設定後にPCからシリアルケーブルを抜くと電源が落ち、時刻がリセットされてしまいます。PCから切り離して（スタンドアロンで）時刻を保持したまま動作させたい場合は、下記の手順に従って電源供給を切り替えてください。

**設定に必要なもの**
- M5Stack用スタンディングベース（給電・スタンド用）
- USB Type-Cケーブル × 2本（PC接続用 ×1、外部電源給電用 ×1）
- 外部電源（USB ACアダプターやモバイルバッテリーなど）

**設定手順**

1. PC側でシリアルモニタ（Arduino IDEのシリアルモニタ）を起動します。(Arduino IDEのTools -> Serial Monitorを選択すると、ウィンドウの下部にシリアルモニターが表示されます。)
2. M5StackをPCとUSB接続し、シリアルモニタから次の形式で送信します。

   ```
   TIME 2026-08-17 09:00:00
   ```

   TIMEは、M5Stackの時計を合わせる命令です。「年-月-日 時:分:秒」の形で送ります。

   **送り方（ここでつまずきやすいので、順番どおりに）**：
   1. シリアルモニタの**上部にある入力欄**をクリックします（マイコンからのメッセージが流れてくる欄とは別の、1行だけの入力欄です）。
   2. **入力欄の右にある改行の設定を「New Line」（または「Both NL &amp; CR」）にします。**
      ここが **「No Line Ending」（改行なし）のままだと、送信しても何も起きません**。
      M5Stack側は「行の終わり」の合図を受け取って初めて命令を読み取る作りになっているためです。
      押しても無反応のときは、まずここを疑ってください。
   3. `TIME 2026-08-17 09:00:00` のように入力して、**Enterキー**（または入力欄の右の送信ボタン）を押します。

3. 「clock set OK: <設定後の時刻>」というエコーバックが返るので、**手元の時計と一致しているかを必ず目視で確認します**。
4. 年月日・時分秒のいずれかが範囲外の値だと、時計は変更されずに次のメッセージが返ります。

   ```
   NG: 値が範囲外です。 usage: TIME 2026-08-17 09:00:00
   ```

   この場合は入力し直してください。範囲内での入力ミス（日付を1日間違える等）は時計自体が変わってしまうため、手順2のエコーバックで気づくことが唯一の手がかりです。実在しない日付（例: 2月31日）は自動的に繰り上がった日付（3月3日）として設定されてしまうので、これもエコーバックの目視で確認してください。
5. 設定に成功すると画面上部の赤い警告が消え、時刻表示に変わります。以後の `LOG.CSV` の `clock` 列が `set` になります。
6. エコーバックの時刻が手元の時計と一致し、画面の警告が消えていることを確認します。

**外部電源への切り替え（PCからの切り離し）**
時刻を保持したままPCから切り離すため、以下の順番で操作を行ってください。**順番を間違えると電源が落ち、時刻がリセットされます。**

1. スタンディングベースのUSBポートに2本目のUSBケーブルを接続し、外部電源（ACアダプター等）から給電を開始します。
2. 本体側面に挿さっているPCへのUSBケーブルを静かに抜きます。

**完了チェック**：PCから切り離しても時計が動き、センサーからの情報を取得できているようならA-6は完了です。

---

## B. 常設期間の毎日チェック（8/26〜）

教室で最初に画面を見た人が、次の3点だけを30秒で確認します。

1. 画面のノード行に赤字で「MUOUTOU」（無応答）が出ていないか。
2. 画面上部に赤字の「JIKOKU MISETTEI  (serial: TIME ...)」が出ていないか。
3. 画面右下が緑の「SD OK」か。

異常があれば、Discordの2行報告に書いてください。

> 例：n3がMUOUTOU 180s、他は正常。SDはOK。

---

## C. データ回収（金曜・SDカードの安全な抜き差し）

1. **必ずM5Stackの電源を切ってから**SDカードを抜きます。通電中に抜くと以後の記録が止まり、カードを戻しても復帰しません（再起動が必要です）。
2. PCで `LOG.CSV` を、そのPCの `analysis/` フォルダへコピーします（バックアップを兼ねます）。
3. **コピーした `LOG.CSV` を、Discordの進捗報告チャンネルに添付して投稿します。** これがデータ分析担当への受け渡しになります（実測データはリポジトリには入れない決まりなので、Gitでは届きません）。
4. SDカードを戻して電源を入れ、画面右下が「SD OK」になることを目視します（「SD NG」のままなら電源を入れ直してください）。
5. 再起動で時計が消えるため、TIMEコマンドを再送します（手順はA-6を参照してください）。エコーバックの時刻と画面の時刻表示を確認します。

**完了チェック**：`LOG.CSV` が `analysis/` フォルダにコピーされ、**Discordに投稿してデータ分析担当へ渡してあり**、画面が「SD OK」かつ正しい時刻表示になっていればC章は完了です。

---

## D. 停電・電源断のあと

受信・画面表示・SD記録は、電源が復帰すれば自動的に再開します（手動操作は不要です）。手動で必要になるのは時刻設定だけです。TIMEコマンドの再送手順はA-6を参照してください。

PCやUSBケーブルが教室に無い日に備えて、教壇のM5Stack付近に予備のUSBケーブルを常備しておいてください。

---

## E. テスト送信するときの注意（開発者向け）

手組みのテストパケットを送る場合は、`docs/data-contract.md` のペイロード（1回の送信で運ぶデータの中身です）契約どおりの完全なJSON（「項目名:値」をカンマで並べる、機械が読み間違えないためのデータの書き方です。`v`・`id`・`seq` は必須、正常時は `t`・`h`、異常時は `err`）で送ってください。契約と違う形式のパケットは集約側でdrop（破棄）として数えられ、`LOG.CSV` には記録されません。

---

困ったときは、自己判断で強引に進めず、企画者に状況を伝えて相談してください。

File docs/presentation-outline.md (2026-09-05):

# 校内発表 構成案 — 教室の温度ムラ「見える化」

- 想定枠：**発表10分 + デモ + 質疑**です（時間配分の詳細は【要確認】です。目安として本文中に記載しています）。
- 発表日：**2026年9月11日（金）15:10〜**に確定しました（9/2に確定。会場は普段の教室で、授業終了の5分後にその場で始めます。機材は常設のまま使い、スライドは各席のモニターに投影します。マイクの可否は前日に分かり、借りられなければ地声です）。制作は9/4で終了し、以後は発表準備だけです（9/2のA/B相談でA案に合意）。発表までの段取りと当日配る1枚資料は [docs/final-week.md](final-week.md) を参照してください。
- この文書は「発表とりまとめ」担当が作るスライドの土台です。決定事項ではなく叩き台として扱い、チームで合意しながら埋めていきます。

## 0. 前提（この構成案が拠り所にしていること）

- チームは訓練校未経験メンバー中心＋企画者です。開発期間は8/17（Day 0）〜9/4（完成デモ+KPT。KPT＝ふりかえりの型で、Keep（続けること）・Problem（困ったこと）・Try（次に試すこと）の3つをまとめます）の約3週間です（進み具合により最大1週間の延長の可能性があり、〜9/11まで延びる場合があります）。
- 役割は、ノード担当（全員1人1台）、集約表示オーナー（メンバー1名）、データ分析、発表とりまとめ、筐体です。
  - ノードとは、教室に置く測定係の小さなコンピューターのことです。ESP32（無線通信ができる小型マイコン。マイコン＝プログラムで動く小さなコンピューター）＋温湿度センサーのセットで、n1〜n4の4台あります。
  - 集約とは、4台のノードからデータを受け取ってまとめる係のM5Stack（画面つきの小型マイコン。教壇に置いて受信データを表示・記録します）のことです。
  - データ分析にはSQLite（ファイル1つで使える小さなデータベース。訓練校で学習済み）を使います。
- データ契約（`docs/data-contract.md`）は、並列開発を支えた土台という位置づけです。
- 公開リポジトリ（リポジトリ＝プロジェクト一式の保管場所。フォルダごと、変更履歴つきで置いておく場所です）のため、学校名や教室が特定される情報はスライドにも書かないようにします（写真を使う場合は要チェックです）。

---

## 1. スライド構成（枚数目安）

10分トークの目安として、1枚あたり40〜60秒換算で組んであります。実際の分量はリハーサルで調整します。

| # | セクション | 枚数目安 | 中身のねらい |
|---|---|---|---|
| 1 | 表紙 | 1枚 | プロジェクト名・チーム名・日付 |
| 2 | 課題：体感のばらつき | 1〜2枚 | 「教室の中でも場所によって暑い/寒いと感じる」を、誰もが実感できる形で提示します。数値ではなく“あるある”から入ります |
| 3 | アプローチ：見える化 | 1枚 | 体感のばらつきを主観のままにせず、複数地点のセンサーで数値化・可視化する、という方針転換を示します |
| 4 | システム構成 | 2〜3枚 | ノード（ESP32+SHT31）→ ESP-NOW → 集約（M5Stack+SD）の全体図。データの流れが一目でわかる図を1枚は必ず入れます |
| 5 | チーム開発の進め方 | 2枚 | 未経験メンバー×3週間という制約でどう分担・並列化したかを説明します。AIルール4つと、その狙いも紹介します |
| 6 | 運用データと分析 | 2〜3枚 | 実測した○日間のデータ（時間帯×場所）。グラフ中心、生データの羅列は避けます |
| 7 | 改善提案 | 1〜2枚 | データから読み取れた傾向に基づく、具体的な提案 |
| 8 | 学び（KPT） | 1枚 | Keep / Problem / Try を1枚にまとめます |
| 9 | まとめ・謝辞 | 1枚 | 一言まとめ＋協力してくれた人へのお礼 |
| 付録 | 役割分担 | 1枚 | 本編では使わず、質疑で聞かれたら出します |

**合計目安は、本編12〜16枚＋付録1枚です。**【要確認】実際の持ち時間（10分ちょうどか、前後に幅があるか）に応じて調整します。

### 各セクションのメモ

**2. 課題（体感のばらつき）**
- 「同じ教室なのに席によって暑い/寒いと感じたことは？」という問いかけから入ると、聞き手を巻き込みやすくなります。
- ここではまだセンサーの数値は出しません。あくまで“体感”の話にとどめます。

**3. アプローチ（見える化）**
- 体感は人によってズレます。そこで、客観的な数値で複数地点を比較できるようにする、という一段だけの転換を明確に伝えます。
- 「なぜIoTで／なぜ自作なのか」に軽く触れておくと、4章の伏線になります。

**4. システム構成**
- ノードはESP32-DevKitC-32E＋AE-SHT31（温湿度センサー。SHT31＝温度と湿度を測るセンサー部品の型番です）を使います。30秒周期でESP-NOW（WiFiルーターなしでESP32どうしが直接データを飛ばせる無線のしくみです）でユニキャスト（その場の全員に向かって叫ぶのではなく、宛先を1台決めて送る方式です）送信します。
- 集約はM5Stack Basicです。受信してSDカードのCSV（カンマ区切りの表形式ファイル。Excelやスプレッドシートでそのまま開けます）に1行ずつ記録し、画面にも表示します。
- 「なぜESP-NOWか」はここで一言触れておくと、質疑の時間短縮になります（詳細は3章のQ&Aへ）。
- 図は`docs/`配下に既にある構成図があれば流用し、なければ発表とりまとめ担当が新規作成します。

**5. チーム開発の進め方**
- 未経験メンバーが1人1台のノードを並行して作れた理由は、データ契約（送信フォーマットを最初に固定したもの）とノード用の共通テンプレート（`firmware/node-template/`）です。
- Git運用は、feature branch（ブランチ＝本体（main）に影響を与えずに作業するための、枝分かれした作業用コピーです）→ PR（Pull Request＝「この変更を本体に取り込んでください」という提案です。チームの誰かが確認してから取り込みます）→ 企画者レビュー → マージ（提案された変更を本体に取り込むことです）という流れです。mainへの直接push（自分のPCでの記録をGitHub側に送って反映することです）はありません。
- AIルール4つをそのまま紹介します。
  1. 共通テンプレートを使う
  2. データ形式の契約を守る
  3. 説明できないコードはマージしない（PR説明欄に自分の言葉で書く）
  4. AIを使った箇所はREADMEに明記する
- 「軽量な進め方を選んだ理由」の言葉の骨子は、未経験者中心・実質3週間という制約の中で、重い計画駆動のプロセスより「先に約束事（データ契約・共通テンプレ）だけ固めて、あとは各自が短いサイクルでPRを出す」やり方の方が、詰まった時にすぐ軌道修正できるためです。金曜ごとの中間デモ（8/21・8/28）を合流ポイントとして挟んでいるのも同じ理由です。
- 【要確認】このセクションを「アジャイル」という言葉で説明するかどうかはチームで相談します（訓練内容と用語がリンクしているかどうかによります）。

**6. 運用データと分析**
- 「○日間」の日数は、実際の運用開始（8/26〜）から発表準備時点までの経過日数で確定します。【要確認】
- 時間帯×場所のクロス集計（例：朝/昼/放課後 × ノード設置地点）をグラフ1〜2枚で見せます。ヒートマップ的な見せ方が向いていそうです。
- 追加の校正（キャリブレーション＝基準になる温度計と並べて測ってセンサーごとのズレを調べること）は実施していません。SHT31が出荷時に校正済みであり、手元で用意できる温度計ではかえって精度を落とすためです（理由は想定問答3）。画面表示・CSV・分析のすべてが生値（センサーが返した値そのまま）で統一されています。
- なお、このプロジェクトで効いてくる誤差はセンサーの個体差（±0.2℃程度）よりも、**設置条件による差のほうが桁で大きい**です（基板の自己発熱・ケース内の熱こもり・日射・エアコンの吹き出し位置で1〜2℃）。聞かれたらこの順序で説明します。
- ノードの設置場所名は学校が特定されない表現にします（「窓際」「廊下側」など役割ベースの言い方に寄せます）。

**7. 改善提案**
- ここは実データが出てからでないと書けない枠です。プレースホルダとして「傾向A→提案A」の型だけ用意しておき、8/26以降の常設記録データが揃い次第、データ分析担当が中身を詰めます。
- 提案は必ず「このデータからこう読み取れる」という根拠とセットにします（感想ベースにしません）。

**8. 学び（KPT）**
- 9/4の完成デモ+KPTで出た内容をそのまま持ってくる想定です。今の時点では空欄です。

---

## 2. デモの段取り

### ライブデモ（うまくいく前提の手順）

1. 常設のままの集約M5Stackとノード4台をそのまま使います（会場は普段の教室なので持ち込みも電源投入もありません）。
2. 画面に気温・湿度・最終受信からの経過秒が表示される様子を見せます。
3. 可能ならその場でノードに軽く息を吹きかける、または手で覆うなどして数値が動く様子を見せ、「ちゃんとリアルタイムで反応している」ことを実感してもらいます。
4. SDカードを抜いてPCに挿し、`LOG.CSV`の中身をそのまま見せます（生データがある、という安心感を出します）。
5. 時間が許せば、データ分析担当のSQLite集計・グラフ画面を軽く見せます。

### リスクと対策

- 会場は普段の教室に確定し、機材も常設のまま使うので、会場での通信テストは不要です（当初は会場が違う場合にESP-NOWの電波状況を確かめる予定でした）。かわりに、授業終了から発表まで5分しかないため、**当日の準備は「確認」だけ**にします（docs/final-week.md 4章）。
- 起動直後は最大30秒（1周期）表示が動かないので、「今データを待っています」と口頭でつなぎます。

### バックアップ運用（ライブが失敗した場合）

- 運用期間中（8/26以降）にM5Stackの画面や実際の動作を**事前に動画で撮影**しておきます（スマホでの手持ち撮影で可）。
- ライブデモが不通・機材トラブルの場合は、司会役が「今はこう動いています」と一言添えたうえで即座に録画へ切り替えます。切り替えの合図と担当者をチームで事前に決めておきます。
- スライドの該当ページに動画をあらかじめ埋め込む、またはすぐ再生できる状態にしておき、その場で探さないようにします。
- CSVの実データも、スクリーンショットをスライドに保険として仕込んでおきます（SDカードの抜き差しが会場で失敗しても止まらないようにするためです）。
- 【要確認】バックアップ動画の撮影担当・撮影日をチームで割り振ります。

---

## 3. 想定質問と答えの骨子

| # | 想定質問 | 答えの骨子 |
|---|---|---|
| 1 | なぜESP-NOW？ Wi-Fiじゃダメだったの？ | 学校のWi-Fiに接続する手間や制約がなく、宛先を固定したペアで直接やり取りできるためです。個人情報を含まない環境データなので、暗号化なしという単純な構成を選べました。 |
| 2 | 精度はどれくらい出るの？ | センサーはSHT31（秋月AE-SHT31）です。カタログ上の精度は、**温度が typ.（標準的な値として）±0.2℃、湿度が typ. ±2%RH** です（メーカーSensirionの製品ページ https://sensirion.com/products/catalog/SHT31-DIS-B より。測定範囲は −40〜125℃／0〜100%RH）。この ±0.2℃ は typ.（標準的な値）であって最大値ではない点に注意してください。SHT31は出荷時に個体ごとの校正が済んでいるため、追加の校正はしていません（理由は想定問答3）。 |
| 3 | 校正はしたの？ | **していません。実測して不要と判断しました。**まず実データで確かめました——誰もいない休日（空調停止・人の出入りなし）の5,741件で4台を突き合わせたところ、**台どうしの差は最大でも0.18℃**でした。これは今回見たい差（授業時間の平均1.9℃・最大4.3℃）の**10分の1以下**なので、補正を入れても結論は変わりません。背景として、SHT31は出荷時に個体ごとの校正が済んでいて、補正値がセンサー内部に書き込まれています（Sensirion公式データシート SHT3x-DIS（2022年12月・Version 7）の図1の説明文に *factory calibrated, linearized and compensated* と明記されています。https://sensirion.com/media/documents/213E6A3B/63A5A569/Datasheet_SHT3x_DIS.pdf ）。そのうえで校正し直すには、基準にする温度計のほうが**十分に正確**でなければ意味がありません。ところが市販の温度計はほとんどが ±1℃程度の製品で、typ. ±0.2℃のSHT31よりも粗いです。それを基準に補正すると、**基準器側の誤差をこちらに持ち込むだけ**になります。そのため記録・画面表示・分析のすべてを生値のまま統一しました。今回見たいのは「同じ時刻に教室のどこが暑いか」という**地点どうしの差**であり、4台とも同じ型のセンサーなので、絶対値のわずかなズレは結論を変えません。なお、ケースに入れたことで絶対値が何℃持ち上がるかは測っていません（そのための並走測定は行わない判断です→Issue #49）。見たいのは同時刻の地点どうしの差なので、全台に共通して乗るズレは結論を変えません。 |
| 4 | AIに書かせたの？ 自分で作ったと言えるの？ | AIは使いましたが、丸投げのコピペではありません。共通テンプレート・データ契約という土台を先に決め、各自が自分のPRで「なぜこの実装にしたか」を説明できることをマージ条件にしました。AI利用箇所はREADMEに明記しています。 |
| 5 | 費用はどれくらいかかった？ | 秋月での部材発注（8/1時点）が¥13,110、別途microSDが約¥1,000でした。合計で概算¥14,000程度です。【要確認：その後の追加購入があれば反映】 |
| 6 | データはどうやって分析したの？ | M5Stack側でSDカードにCSVをそのまま記録し、訓練で習ったSQLiteを使って集計・分析しています。生データと分析結果を分けて扱っています。 |
| 7 | 未経験のメンバーで3週間しかないのに、どうやって分担したの？ | 最初にノード⇔集約間の「データ契約」を固定し、共通テンプレートを用意したことで、各自が自分のノードを並行して作れる状態を作りました。8/21に中間デモで一度合流し、8/25に全ノード稼働のすり合わせをしています。 |
| 8 | 次に改良するなら何をする？ | 【要確認：チームで合意した上で埋める】想定される方向性としては、M5StackにRTC（電源を切っても時刻を覚えていられる時計の部品です）がなく、時刻を手動設定している点の解消、筐体の作り込み、ノード台数の拡張などです。 |

---

## 4. 発表資料作成の分担ルール

- **スライド本体（構成・文章・図の作成）は「発表とりまとめ」担当が作ります。** 企画者はスライド本体を作りません。
- 各セクションの中身は、担当ロールが情報を出す形にします。
  - システム構成（4章）→ ノード担当・集約表示オーナーが技術情報を提供します
  - チーム開発の進め方（5章）→ 全員の実体験＋企画者が事実確認のみ協力します
  - 運用データと分析／改善提案（6〜7章）→ データ分析担当が中身を作成します
- 企画者の関わりは**レビューのみ**です（事実確認、公開リポジトリとして問題ある記述のチェックなど）。文章そのものを書き直すことはしません。
- この文書（`docs/presentation-outline.md`）自体は構成の叩き台です。

### 何で作って、どこに置くか

- **スライドは Google スライドで作ります。** 全員がGoogleアカウントを持っていて（アンケートで使いました）、インストールが要らず、リンク1つで共有・共同編集できるためです。使い慣れたソフトが別にある場合は企画者に相談してください。
- 作ったら、**Discordの資料リンクのチャンネルに共有リンクを貼ります**（共有設定は「リンクを知っている全員が閲覧可」で十分です）。ファイルそのものはリポジトリには入れません。
- **構成図（4章）は、スライドソフトの図形機能で四角と矢印を並べれば十分です。**作図の専用ソフトは要りません。README.mdの先頭に図の元になる記述（Mermaid）がありますが、これは画像ではないので、見ながら描き起こす形になります。画像が必要なら企画者に言ってください。

### 各章の中身をいつまでに集めるか

スライドは1人では埋まりません。**他の担当に情報をもらう締切を、3週目の月曜キックオフで決めます。**目安は次のとおりです。

| 章 | 出す人 | 目安 |
|---|---|---|
| 4. システム構成 | ノード担当・集約表示オーナー | 3週目の火曜まで |
| 6〜7. 運用データと分析・改善提案 | データ分析担当 | 3週目の水曜まで |
| 5. チーム開発の進め方 | 全員（体験談）＋企画者が事実確認 | 3週目の水曜まで |

受け渡しはDiscordの資料リンクのチャンネルで行います。締切を過ぎているものは、遠慮せず催促してください（催促は仕事のうちです）。

## 5. 変更履歴

- 初版（2026-08-01）：構成案ドラフト。
- 2026-08-15：想定質問2の【要確認】だったセンサー精度を、メーカーの製品ページで確認した数値（温度 typ. ±0.2℃／湿度 typ. ±2%RH）に置き換えました。
- 2026-09-03：発表日を9/11（金）15:10に確定し、仕上げ週の段取り（final-week.md）へのリンクを追加しました。

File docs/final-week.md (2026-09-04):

# 9/4→9/11 仕上げの段取り（完成デモ・KPT・データ回収・発表）

制作は9/4で締め、9/11（金）15:10から普段の教室でそのまま発表します。機材は常設のまま動かしません。
メンバーにお願いする作業は、この期間で合計2〜3時間です。

## 1. 日程

| 日 | やること | 誰が |
|---|---|---|
| 9/4（金） | 完成デモ＋KPT（2章） | 全員 |
| 9/7（月） | キックオフ15分：スライドの残りと担当を確認。AI活用の記録の転記PR | 全員／発表とりまとめ |
| 9/8（火） | 訓練休。作業なし | — |
| 9/9（水） | 放課後すぐ**最後のデータ回収**（3章）→ 通し練習1回目（9/4時点のグラフのまま） | 回収＝集約表示オーナー、通し＝全員 |
| 9/9夜〜9/10朝 | 最終データで集計・ヒートマップ更新。「○日間・○件・最大差○℃」を #資料リンク に書く | データ分析 |
| 9/10（木） | グラフとスライドの差し替え → 通し練習2回目（時間計測・スマホ録画＝バックアップ動画 #28）。1枚資料の確認もこの日まで | 全員 |
| 9/11（金） | 発表（4章） | 全員 |

記録は9/10まで続けますが、発表に使うのは9/9回収分までです。分析が9/10朝に間に合わなければ、9/4時点のグラフで発表します。

## 2. 9/4（金）完成デモ＋KPT（15:10〜16:10）

| 時間 | 内容 |
|---|---|
| 15:10〜15:27 | **完成デモ**。本番と同じ順：①M5Stack画面（4ノード受信）②ノード1台に息を吹きかけて温度・湿度が動く（下の注意） ③グラフ画面 ④SDの `LOG.CSV` を開く ⑤ヒートマップ ⑥アンケート速報。①〜⑤が通れば完成 |
| 15:27〜15:57 | **KPT**。7分：各自でGoogleスライドに書く（Keep・Problem各2つ以上）／15分：1人3分で読み上げ、反論なし／6分：Tryを絞る（発表までに1〜2、次回チーム開発なら3まで）／2分：スライド8枚目に載せる3行を確認 |
| 15:57〜16:05 | **決めごと**（下の表） |

息を吹きかけたデータは `LOG.CSV` に残ります。9/4のデモは分析に使う期間の中なので、**吹きかけたノードIDと時刻をDiscordの2行報告に書き**、分析担当はその前後10分を除外します（例：`WHERE NOT (node_id='n3' AND recv_time BETWEEN '2026-09-04 15:12' AND '2026-09-04 15:32')`）。9/9以降の通しと9/11本番は回収のあとなので、気にせず吹きかけて大丈夫です。
| 16:05〜16:10 | Discordに2行報告、機材を常設に戻す（SDを戻して電源ON→SD OK→TIME再送） |

KPTの書き方：人ではなくやり方について書く。週5〜8時間を超えていなかったかも全員に聞く。
詰まったときの問い：データ契約を先に固定したのは効いたか／PRレビュー待ちで困ったか／AIルール3・4は守れたか／校正しない判断（#24）は納得できたか／毎日の30秒チェックは回ったか／9/2の「9/4で締める」判断は早かったか遅かったか。
READMEの決めごと（Git運用・AIルール・週次リズム）は「このまま／変える」だけ聞き、変えるなら企画者がPRします。
記録：発表とりまとめ担当が当日中にIssue #29へ貼って閉じる。スライド8枚目には各1〜2行だけ載せます。

| 決めること | 企画者案 |
|---|---|
| 通し練習 | 9/9・9/10の2回。会場も機材も同じなので通信テストはしない |
| 9/11の5分（15:05〜15:10） | 各席モニターへの投影＝発表とりまとめ、1枚資料の配布＝企画者、M5Stack画面の目視＝集約表示オーナー |
| 当日の役割 | 話す＝発表とりまとめ＋各章の担当、デモ操作＝集約表示オーナー、録画切替の合図と時間管理＝企画者 |
| 9/9の回収当番 | 集約表示オーナー（これまでどおり） |
| 1枚資料 | 企画者が作り9/10までに共有、全員で確認（5章） |
| 発表後の記録 | 9/11の発表で終了（SDを抜いても時刻を戻さなくてよい） |

## 3. 9/9（水）データ回収

手順は docs/first-boot-check.md C章のとおりです。放課後すぐに始めて15分で終えます。

1. 電源を切ってからSDを抜く → 学校PCの `analysis/` に `LOG.CSV` をコピー
2. `LOG.CSV` を #進捗報告 に添付。本文に「回収時刻・行数・最終行の recv_time」を書く
3. SDを戻して電源ON → 「SD OK」を確認 → TIMEコマンドを再送して時刻を目視

## 4. 9/11（金）発表当日

授業終了から5分で始めるので、当日は準備ではなく確認だけです。

| いつ | やること | 誰が |
|---|---|---|
| 授業中 | M5Stackが「SD OK」・4ノード受信・時刻表示になっているか見ておく | 企画者 |
| 最後の休み時間 | 発表PCでスライドとバックアップ動画を開いておく。マイクを借りられていれば受け取る（可否は前日判明、なければ地声） | 発表とりまとめ |
| 15:05〜15:10 | 投影・配布・画面の目視（2章の分担） | 3人 |
| 15:10 | 発表10分＋デモ＋質疑。ライブデモが止まったら企画者が「録画に切り替えます」と言い、発表とりまとめが動画を再生 | 全員 |
| 終了後 | ノードは譲渡希望者へ、M5Stackは企画者が持ち帰る | 企画者 |

## 5. 当日配るA4・1枚資料（企画者が作成）

スライドの縮小版ではなく「持ち帰って見返す用」です。Googleスライド（A4縦）→PDF→印刷。学校名・教室番号・本名は書きません。

| 区画 | 中身 |
|---|---|
| 何を作ったか | 1文＋構成図（ノード4台→ESP-NOW→M5Stack→SD→分析） |
| 結果 | ヒートマップ1枚＋「○日間・○件・最大差○℃」（データ分析担当の最終値と同じ数字） |
| わかったこと・提案 | 「傾向→提案」を2組まで、根拠つき |
| 作り方 | データ契約を先に固定／共通テンプレート／PRレビューとAIルール4つ |
| 機材と費用・チーム | 部材費 約¥14,000、役割表（GitHubユーザー名）、リポジトリURLとQR |

9/9夜に仮の数字で共有 → 9/10朝までに分析担当が最終値を出す → 9/10の通し前に差し替えて全員で確認 → 印刷。

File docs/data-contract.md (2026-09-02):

# データ契約 v1 — 教室の温度ムラ「見える化」

- 状態：**企画者承認済み・v1確定（2026-08-10）→ Day 0（8/17）でメンバーに説明**
- これは「ノード ⇄ 集約M5Stack」の**約束事**です。ここさえ揃っていれば、4人が並列で作っても最後に必ず合流できます。
- **「v1」の v はバージョン（版番号）のことです。** 資料の「第1版・第2版」と同じで、いまは第1版なので v1 です。**ルールを変えたいときは、必ずチームで合意してから版番号を1つ上げます**（v1→v2。勝手に項目を足しません）。こうすると、新旧のルールが混ざっても「どの版で作られたデータか」を区別できます。
- このファイル（`docs/data-contract.md`）が正本です。
- ノードとは、教室に置く測定係の小さなコンピューターです（ESP32＋温湿度センサーのセット）。M5Stackとは、画面つきの小型マイコンで、教壇でデータを受け取る集約役です。

## 1. 全体のルール

| 項目 | 決め | つまりこういうこと |
|---|---|---|
| 送信周期 | **30秒に1回** | 各ノードは電源が入ってから30秒おきに測って送ります。ノードどうしで送るタイミングを合わせる必要はありません |
| 通信方式 | ESP-NOW **ユニキャスト** | ESP-NOW＝WiFiルーターなしでESP32どうしが直接データを飛ばせる無線のしくみです。ユニキャスト＝「その場の全員に向かって叫ぶ」のではなく、**宛先を1台決めて送る**方式です。宛先は集約役のM5Stackです |
| 宛先の指定 | M5Stackが起動画面に自分のMACアドレスを表示 → 各自が `config.h` に書き写します | MACアドレス＝機器1台ごとに工場出荷時から付いている固有の番号（**機器の住所**のようなもの）です。`config.h`＝各ノードのプログラムの中にある設定ファイルです。書き写しは8/17週の放課後に行います（初期タスクの13番です） |
| チャンネル | **1に固定** | チャンネル＝無線の通り道の番号です（トランシーバーの「チャンネルを合わせる」と同じです）。送る側と受ける側が同じ番号になっていないと届きません |
| 暗号化 | なし | 暗号化＝通信の中身を他人に読めなくする処理です。ここを流れるのは温度と湿度だけで個人情報がないので、設定が簡単な「なし」を選びます |
| 送信失敗時 | 「届いたよ」の返事がなければ**1秒後に1回だけ再送**。それでもダメなら諦めて次の周期に任せます | しつこく再送しないのは、30秒後にはどうせ次の測定データが来るからです。1回分くらい欠けても分析には響きません（欠けたこと自体は下の `seq` で分かります） |
| 時刻 | **ノードは時計を持ちません**。データが届いた瞬間に、M5Stackが自分の時計で時刻を付けます | 時計を持つのは集約M5Stackの1台だけです。ノード4台の時計をぜんぶ合わせる手間をなくすための決めです |

## 2. 送る中身（ノード → 集約）

データは **JSON（ジェイソン）** という書き方で送ります。JSONは「`項目名:値`」をカンマで並べる、機械が読み間違えないための書き方です。見た目は暗号っぽいですが、読み方は簡単です。

正常時に送るのはこの1行です：

```json
{"v":1,"id":"n1","seq":123,"t":26.4,"h":55.2}
```

日本語にすると——**「契約の版は1。私はノードn1。これは起動してから123回目の送信。気温26.4℃、湿度55.2%」**です。

センサーの読み取りに失敗したときは、気温・湿度の代わりに `err` を入れて送ります：

```json
{"v":1,"id":"n1","seq":124,"err":"sensor"}
```

日本語にすると——**「契約の版は1。私はノードn1。124回目の送信。センサーの読み取りに失敗した」**です。

### 各項目の意味

| 項目名 | 入る値 | いつ入れる | 意味 |
|---|---|---|---|
| `v` | 整数（いまは必ず `1`） | 毎回 | この契約の**版番号（バージョン）**です。受け取る側はこの数字で「どの版のルールで作られたデータか」を見分けます。ルール変更でv2になったら、更新前のノードのデータ（`v:1`）が混ざっても区別できます |
| `id` | 文字（`"n1"`〜`"n4"`） | 毎回 | **ノードの名前**です。どのノード（＝どの場所）の測定かを表します。各ノードの `config.h` に固定で書き込みます。名前と設置場所の対応表はREADMEで管理します |
| `seq` | 整数（0から+1ずつ） | 毎回 | **通し番号**です。送信のたびに1ずつ増えます。受け取った側で番号が飛んでいたら（例：123の次が125）「途中の1回が電波の途中で消えた」と分かります。ノードを再起動すると0に戻って構いません |
| `t` | 数値（小数1桁） | 正常時のみ | **気温（℃）**です。センサーSHT31が返した生の値をそのまま送ります（ズレの補正は集約側の仕事です。ノードでは何もしません） |
| `h` | 数値（小数1桁） | 正常時のみ | **湿度（%）**です |
| `err` | 文字 | 失敗時のみ | `"sensor"`＝センサー読み取り失敗の印です。**失敗しても黙らずに送る**のがポイントで、「何も送ってこない＝ノードごと止まっている」と「errを送ってくる＝ノードは生きていてセンサーだけ故障」を見分けられます（生存報告を兼ねます） |

- **この6個以外の項目を勝手に足しません**。足したくなったらチームで合意 → 版番号を上げます（v1→v2）。
- 1回分のデータは約60バイトです。ESP-NOWが一度に送れる上限（250バイト）の1/4以下なので余裕は十分です。

## 3. 集約側の記録（SDカード・CSV）

- CSV＝**カンマ区切りの表形式ファイル**です。Excelやスプレッドシートでそのまま開けます。
- ファイルはSDカードの `/LOG.CSV` です。**1件受け取るたびに1行追記して、その場でSDカードへの書き込みを確定させます**（＝突然電源が切れても、消えるのは最大1行だけです）。
- **CSVには生の値を記録します**。追加の校正（＝基準の温度計と並べて測ってセンサーごとのズレを調べること）は実施しません。SHT31は出荷時に個体ごとの校正が済んでおり、手元で用意できる精度の温度計を基準にするとかえって誤差が増えるためです（`docs/presentation-outline.md` の想定問答3に詳しく書いてあります）。そのため補正値は設定していません（プログラム上のオフセットは4台とも0のままです）。**画面表示・CSV・分析のすべてが生値で統一されています**。どこかの段階だけ値が違う、ということは起きません。

列の並び：`recv_time,clock,node_id,seq,temp_c,hum_pct,status`

| 列 | 意味 |
|---|---|
| `recv_time` | M5Stackがそのデータを**受け取った時刻**（例 `2026-08-21 10:30:15`） |
| `clock` | `set`／`unset`。M5Stackの時計が**設定済みかどうかの印**です。`unset` の間の `recv_time` は仮の時刻なので、分析のときは除外するか後で手補正します |
| `node_id` `seq` `temp_c` `hum_pct` | 送られてきた中身の書き写しです（`err` のときは `temp_c` `hum_pct` を空欄にします） |
| `status` | `ok`＝正常／`sensor_err`＝センサー読み取り失敗 |

例（2行目がセンサー失敗の例）：

```csv
2026-08-21 10:30:15,set,n1,123,26.4,55.2,ok
2026-08-21 10:30:22,set,n3,98,,,sensor_err
```

日本語にすると——1行目は「8/21 10:30:15にノードn1の123回目の送信を受信。気温26.4℃・湿度55.2%で正常」、2行目は「n3の98回目はセンサー読み取り失敗」という意味です。

## 4. 画面表示の目安（参考。契約ではない）

- ノードごとに：最新の気温・湿度＋最後に受信してからの経過秒数を表示します。
- **90秒（3周期）以上データが来ないノードは「無応答」と表示します**。
- 時刻未設定の間は画面に「時刻未設定」警告を常時表示します。

## 5. 変更履歴

- v1（2026-08-01）：初版ドラフト。
- 2026-08-10：決定内容はそのまま、専門用語を知らなくても読めるように説明を全面加筆（版番号は v1 のまま）。
- 2026-08-10：企画者承認。v1として確定。
- 2026-08-11：決定内容はそのまま、文体をですます調に統一。
- 2026-08-11：MACアドレスの書き写し時期の記述を「Day 0」→「8/17週の放課後」に修正（Day 0の計画変更に合わせた、時期の記述だけの変更です）。
- 2026-08-11：状態行の「Day 0でメンバーに説明・承認」を「説明」に修正（契約自体は8/10に企画者承認で確定済みのため。決定内容は変わっていません）。

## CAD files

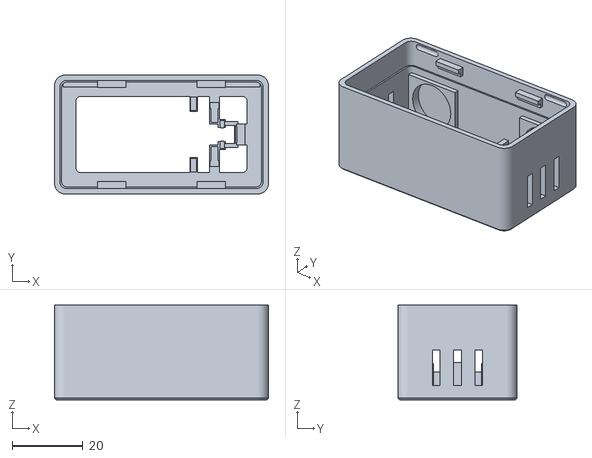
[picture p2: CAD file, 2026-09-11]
hardware/case/stl/node_case_v3_shell_n4.stl
60.3 x 33.5 x 26.7

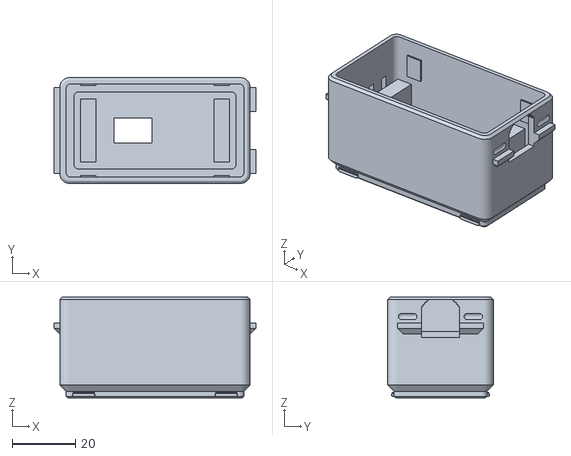
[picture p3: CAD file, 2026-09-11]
hardware/case/stl/node_case_v3_box.stl
64.0 x 33.5 x 32.0

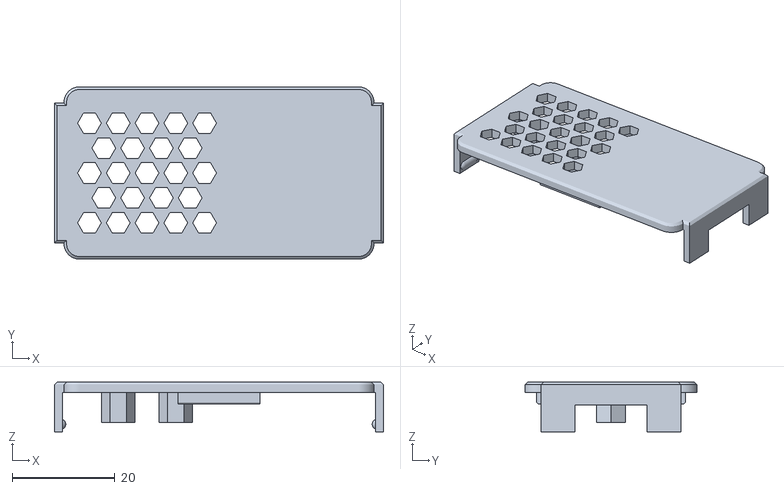
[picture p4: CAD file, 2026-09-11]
hardware/case/stl/node_case_v3_lid.stl
64.0 x 33.5 x 9.70

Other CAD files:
hardware/case/stl/node_case_v3_shell_n3.stl
hardware/case/stl/node_case_v3_shell_n1.stl
hardware/case/stl/node_case_v3_shell_n2.stl

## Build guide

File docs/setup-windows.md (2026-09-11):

# Windows 11 環境構築手順

このリポジトリ（`classroom-temp-map`）でファームウェアを書き込めるようにするための、Windows 11 向けセットアップ手順です。
**リポジトリ**とは、プロジェクト一式の保管場所（フォルダごと、変更履歴つきで置いておく場所）のことです。
**マイコン**とは、プログラムで動く小さなコンピューターのことです。
**ファームウェア**とは、そのマイコンに書き込むプログラムのことです。

IT経験がなくても、上から順番にやれば完了する粒度で書いています。わからない用語が出てきても、書いてある通りにクリック・入力すれば大丈夫です。

**対象者**：ノード担当（全員。**ノード**＝教室に置く測定係の小さなコンピューターです）＋ 集約表示オーナー（M5Stack担当。**集約**＝4台のノードからデータを受け取ってまとめる係、**M5Stack**＝画面つきの小型マイコンです）
**所要時間の目安**：初回は1.5〜2時間（esp32ボードパッケージのダウンロードに時間がかかります）
**前提**：Windows 11（64bit）、インターネット接続、自分のPCの管理者権限（ドライバインストールで必要になることがあります）、GitHubアカウント
**用意するもの**：USBケーブル（データ通信対応のもの。充電専用ケーブルは使えません）、自分の担当ボード（ノード担当は ESP32-DevKitC-32E、集約担当は M5Stack Basic。**ESP32**＝無線通信ができる小型マイコンです）

> **ボードはDay 0（8/17）に配布します。** 手元に届くまでは、ボードをつなぐ確認（3章の接続確認と7章の書き込み）はできなくてOKです。
> 事前宿題の完了基準は「6章のコンパイル（＝書いたプログラムを機械が実行できる形に変換し、文法ミスがないか確かめること。くわしくは6章）が通ること」までで、これはボードなしでできます。

> **学校PCにも、同じ手順で導入します。** 自宅PC分はこの手順書どおり事前宿題として各自で、学校PC分はDay 0（8/17）の残り時間と8/18（火）の放課後に**チームで一緒に**導入します（私有USBメモリ・個人PCは学校ルールで持ち込み禁止のため、インストーラは各自が学校回線で公式サイトからダウンロードします。回線が混まないよう、開始のタイミングをずらします）。**ただし、GitHubアカウントまわり（0章）はアカウントに対して1回やれば済む**ので、自宅で終わっていれば学校PCでは不要です。**学校PCでは1章「Arduino IDE 2.x のインストール」から始めてください**（2つ目のアカウントを作ってしまわないよう注意してください）。また、学校のネットワークは**プロキシ**（外部との通信を中継するサーバーです。くわしくは1-2で説明します）を経由する構成のため、**学校PCでは 1-2 と5章の手順4のプロキシ設定が必須です**（やらないと、Arduino IDEが起動画面のまま止まり、cloneやpushも時間切れで失敗します）。学校PCは1人1アカウントなので、5章の初回pushで出るGitHubの認証は、自宅と同じように各自で行って大丈夫です。管理者権限の画面が出て進めなくなったときは、企画者に声をかけてください（8/17に企画者が学校PC1台で導入できるか下見をしました。1-2と5章の手順4のプロキシ設定は、この下見で判明した学校ネットワークの構成を反映した手順です。もしドライバが学校PCに入れられない場合は、**ボードへの書き込みは自宅PCで行い、書き込み済みのボードを学校に持ってくる**運用に切り替えます）。

手順は0章の確認と、そのあとの1〜8章です。集約担当だけに必要なステップには「（集約担当のみ）」と書いてあります。それ以外は全員共通です。

---

## 0. GitHubアカウントについて

アカウントの作り方そのものは公式の案内が最新なので、ここには置いていません。

このチームで決めていたのは、**コミット（変更内容の記録）に個人のメールアドレスを残さない**という1点です。
GitHubの Settings → Emails →「Keep my email addresses private」をOnにすると
`番号+ユーザー名@users.noreply.github.com` の形の代理アドレスが表示されるので、それを5章のgit設定で使います。
公開リポジトリでは、いちど記録されたメールアドレスは変更履歴に恒久的に残るためです。

---

## 1. Arduino IDE 2.x のインストール

### 1-1. インストールする

1. 公式サイト [https://www.arduino.cc/en/software/](https://www.arduino.cc/en/software/) を開きます。
2. 「Windows」向けのダウンロードボタンを探します（現行バージョンは **Arduino IDE 2.3.10**。サイトを開いた時点でこれより新しいバージョンが表示されていたら、そちらをダウンロードして問題ありません）。ファイル名の目安は `arduino-ide_2.3.10_Windows_64bit.exe` です。
3. 「Just Download」（無料）をクリックしてダウンロードします。寄付を求める画面が出ますが、支払わなくても下の方に無料ダウンロードのリンクがあります。
4. ダウンロードした `.exe` をダブルクリックしてインストールします。表示される画面はすべて既定値のままで進めてOKです（ライセンス同意 → インストール場所 → インストール実行）。途中で「このデバイス ソフトウェアをインストールしますか？」という確認（発行元：Adafruit Industries、Arduino LLC など）が出たら、インストーラー同梱の署名済みUSBドライバなので、すべて「インストール」を選んでOKです。
5. インストール後、Arduino IDE を一度起動します。
   - **自宅PC**：エディタ画面（メニューとコード欄のある画面）が開けば、この章は完了です。
   - **学校PC**：ロゴが脈動する画面のまま止まりますが、**故障ではありません**（インストールをやり直しても直りません）。そのまま右上の✕で閉じて、次の1-2に進んでください。

> 補足：このインストーラーは USB ドライバも一部まとめて入れてくれることがあります。まず手順3（USBドライバ）の「確認」だけ先にやってみて、デバイスマネージャーに `COM` 番号（**COMポート**＝PCがUSB機器と会話するための接続口の番号です。COM3など）が出ていれば、そのステップの手動インストールは不要です。

### 1-2. 学校PCのみ：プロキシを設定する

**自宅PCではこの節は不要です（実行しないでください）。2章に進んでOKです。**

学校のネットワークは、**プロキシ**（外部との通信をいったん引き受けて中継するサーバーです。学校や会社のネットワークでよく使われます）を経由しないと外部と通信できない構成になっています。ブラウザはプロキシの場所を知っていますが、Arduino IDE は知らないため、そのままでは起動時の通信がすべて時間切れになり、ロゴが脈動する画面のまま何分も止まります（2026-08-17の学校PC下見で確認した実症状です）。

ここでは、IDE用の設定ファイルにプロキシの場所を書いて教えます。**学校のシステム設定を変える操作ではありません**——編集するのは自分のユーザーフォルダ内にあるIDE用の設定ファイルで、IDEの設定画面（`基本設定` → `ネットワーク`）が書き込むのと同じファイルです。

1. まず、学校のプロキシの「IPアドレス」と「ポート番号」を控えます。`Windowsキー + I` で設定を開き、`ネットワークとインターネット` → `プロキシ` → 「手動プロキシ セットアップ」の「**編集**」をクリックすると、「プロキシ IP アドレス」（`proxy.example.invalid:8080` のような数字4組）と「ポート」（`8080` のような数字）が表示されるので、**2つともメモします**。メモしたら「キャンセル」で閉じてください（値を変えたり保存を押したりはしません。見てメモするだけです）。
2. まだ一度も Arduino IDE を起動していない場合は、一度起動して✕で閉じます（1-1の手順5です。ロゴ画面のまま止まってOKです。この初回起動で、設定ファイルの置き場が自動で作られます）。すでに起動したことがあれば、いまIDEが閉じていることだけ確認します。
3. `Windowsキー + R` を押し、次を貼り付けてEnterを押します（メモ帳で設定ファイルが開きます）。

   ```
   notepad %UserProfile%\.arduinoIDE\arduino-cli.yaml
   ```

4. 開いた中身を**全部消して**、次の4行に丸ごと置き換えます。

   ```yaml
   board_manager:
     additional_urls: []
   network:
     proxy: http://proxy.example.invalid:8080
   ```

   > **⚠ このままコピーして貼らないでください。** 最後の行の `proxy.example.invalid:8080` と `8080` の部分は、**手順1でメモした自分の学校の値に書き換えます**。行頭の字下げ（半角スペース2個）はこの形のまま崩さないでください。

   （読み下し：下2行が「外部と通信するときは、このプロキシを経由せよ」という指示です。）

5. `Ctrl + S` で保存して、メモ帳を閉じます。
6. Arduino IDE をもう一度起動します。今度はロゴ画面を数十秒以内に抜けて、エディタ画面が開けば成功です。開かない場合は、8章の表を確認したうえで企画者に連絡してください。

---

> プロキシ設定例の `proxy.example.invalid:8080` は説明用です。そのまま接続せず、学校の管理者から案内されたホスト名とポートへ置き換えてください。

## 2. ボードマネージャーURLの追加 → esp32パッケージ 3.3.11 のインストール

1. Arduino IDE を開き、左上メニューの `ファイル`（File）→ `基本設定`（Preferences）を開きます（ショートカット `Ctrl+,` でも可）。

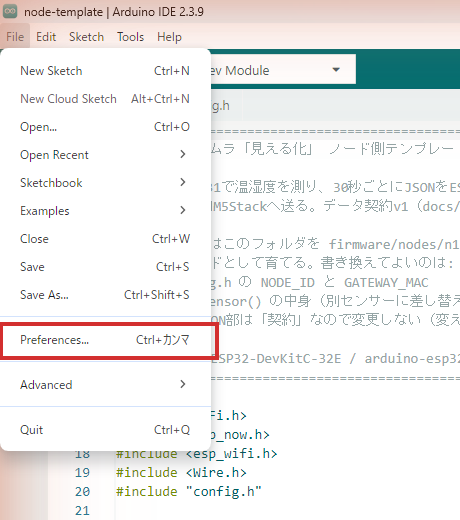
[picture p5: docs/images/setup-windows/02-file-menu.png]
Fileメニューを開いたところ。下の方の「Preferences...」（基本設定）を選びます
   
2. 「追加のボードマネージャのURL」（Additional boards manager URLs）の欄に、以下のURLを貼り付けます。

   ```
   https://espressif.github.io/arduino-esp32/package_esp32_index.json
   ```

   すでに他のURLが入っている場合は、改行またはカンマ区切りで追記します（上書きしないでください）。

3. 「OK」をクリックして設定画面を閉じます。

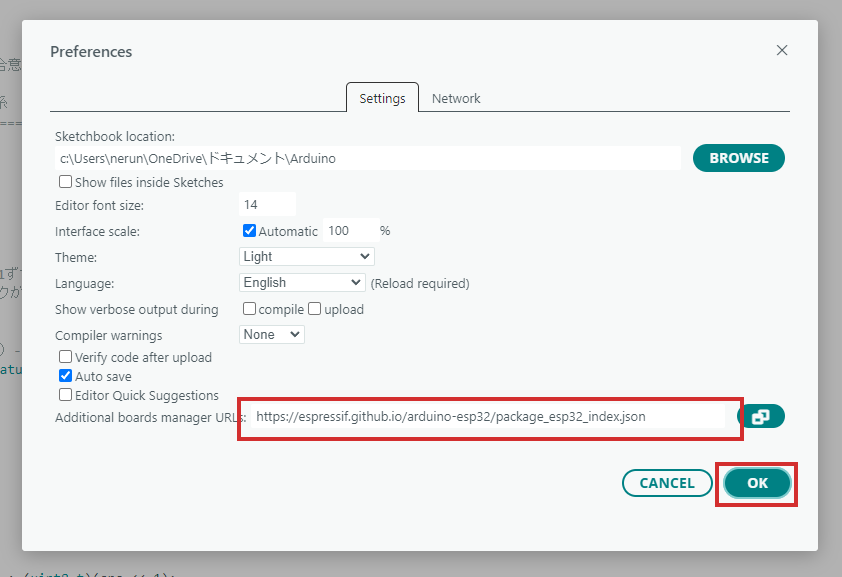
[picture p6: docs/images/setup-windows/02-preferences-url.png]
Preferences画面。下部の「Additional boards manager URLs」欄にURLを貼り付けて、OKを押します
   
4. 左側の縦アイコンの中から「ボードマネージャ」（Boards Manager、四角が積み重なったアイコン）をクリックします。
5. 検索欄に `esp32` と入力すると、「**esp32 by Espressif Systems**」が出てきます。

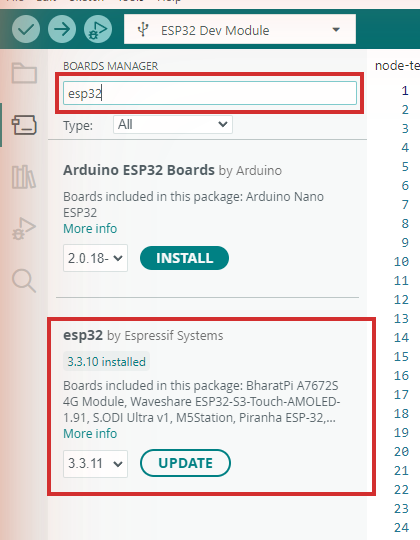
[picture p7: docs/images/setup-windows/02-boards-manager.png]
ボードマネージャの検索欄にesp32と入力し、esp32 by Espressif Systemsのバージョンを3.3.11にしてボタンを押します
   

   ※画像は撮影した環境に導入済みのため「UPDATE」表示ですが、初めてのインストールでは「INSTALL」と表示されます（押すボタンの位置は同じです）。
6. バージョン選択のドロップダウンから **3.3.11** を選び、「インストール」（Install）をクリックします。

   **これは数百MB〜1GB以上のダウンロードになるため、環境によっては10〜30分ほどかかります。** インストール中はPCの電源とネット接続を切らないでください。途中で止まっているように見えても、進捗バーが動いていれば待ってOKです。

7. インストール完了後、一覧に `esp32 (3.3.11)` と表示されていれば成功です。

---

## 3. USBドライバのインストール

> ボードがまだ手元に無い期間（Day 0前）は、この章は**ドライバのダウンロード〜インストールまで**（3-1の手順3〜7）進めておけばOKです。ボードをつないで確認する手順（3-1の手順1〜2と8、3-2）は、Day 0でボードを受け取ってから行ってください。

### 3-1. ノード用（ESP32-DevKitC-32E）＝ CP210x ドライバ（全員）

1. ESP32-DevKitC-32E をUSBケーブルでPCに接続します。
2. `Windowsキー` を右クリックして「デバイスマネージャー」を開きます。「ポート (COM と LPT)」の項目を確認します。
   - すでに `Silicon Labs CP210x USB to UART Bridge (COMx)` のように表示されていれば、ドライバは入っているのでこのステップは完了です。次（3-2または手順4）に進んでOKです。
   - 何も表示されない／「ほかのデバイス」に「!」マーク付きで出ている場合は、以下の手動インストールに進みます。
3. 公式サイト [https://www.silabs.com/software-and-tools/usb-to-uart-bridge-vcp-drivers](https://www.silabs.com/software-and-tools/usb-to-uart-bridge-vcp-drivers) を開きます。
4. 「Downloads」タブから、Windows向けの VCP ドライバ（zip）をダウンロードします。
5. ダウンロードしたzipを右クリックして「すべて展開」で解凍します。
6. 解凍したフォルダの中から `CP210xVCPInstaller_x64.exe`（64bit Windows 11用）を実行し、インストールを進めます。
7. インストール後、PCの再起動を求められたら再起動します。
8. もう一度デバイスマネージャーの「ポート (COM と LPT)」を確認し、`Silicon Labs CP210x USB to UART Bridge (COMx)` が出ていればOKです。この `COMx` の番号は手順7で使うのでメモしておいてください。

### 3-2. 集約用（M5Stack Basic）＝ CH9102 または CP2104（集約担当のみ）

M5Stack Basic は製造時期によって、USB通信用のチップが **CH9102** または **CP2104** のどちらかになっています（見た目では区別できません）。まず上の3-1と同じ手順で CP210x ドライバをインストールした状態でM5Stack Basicを接続し、デバイスマネージャーに `COM` 番号が出るか確認してください。

- **出た場合**：CP2104チップです（CP210xドライバでカバーされます）。追加作業は不要です。
- **出ない／認識されない場合**：CH9102チップです。M5Stack公式ドキュメント [https://docs.m5stack.com/en/download](https://docs.m5stack.com/en/download) のドライバ配布ページから CH9102 用ドライバ（Windows用インストーラ）をダウンロードして実行し、案内に従ってインストールしてください。インストール後、再度デバイスマネージャーで `COM` 番号が出るか確認します。

---

## 4. M5Unified ライブラリのインストール（集約担当のみ）

ノード担当は追加ライブラリ不要のため、このステップは飛ばしてOKです。

1. Arduino IDE の左側の縦アイコンから「ライブラリマネージャ」（本のアイコン）を開きます。
2. 検索欄に `M5Unified` と入力します。
3. 「**M5Unified** by M5Stack」を選び、「インストール」をクリックします。

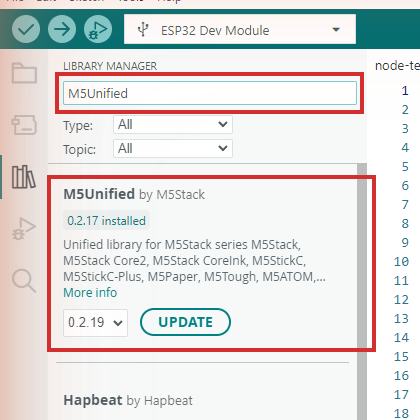
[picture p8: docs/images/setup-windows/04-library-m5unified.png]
ライブラリマネージャの検索欄にM5Unifiedと入力し、M5Unified by M5Stackをインストールします
   

   ※画像は撮影した環境に導入済みのため「UPDATE」表示ですが、初めてのインストールでは「INSTALL」と表示されます。
4. 依存ライブラリ（M5GFXなど）を一緒にインストールするか聞かれたら「Install All」を選びます（M5UnifiedはM5GFXに依存しており、自動で入ります）。
5. インストール完了後、ライブラリ一覧に `M5Unified` が表示されていればOKです。

---

## 5. リポジトリの clone（Git for Windows + VSCode）

ここでは、GitHub上のリポジトリを自分のPCへ丸ごと複製する「**clone（クローン）**」を行います。

1. **Git for Windows** を公式サイト [https://git-scm.com/download/win](https://git-scm.com/download/win) からダウンロードし、インストールします。インストール画面はほぼすべて既定値のままでOKです（「Git from the command line and also from 3rd-party software」が選ばれている状態が既定です。変更不要です）。
2. **VSCode（Visual Studio Code）** を公式サイト [https://code.visualstudio.com/download](https://code.visualstudio.com/download) からダウンロードし、インストールします（Windows x64 User Installer、管理者権限不要のもので問題ありません）。
3. VSCode を開き、メニュー `ターミナル`（Terminal）→ `新しいターミナル`（New Terminal）でターミナルを開きます。**タブ名が「powershell」（プロンプトが `PS C:\...>` の形）であることを確認してください。**「cmd」になっている場合は、ターミナル右上「＋」の隣の「∨」→「既定のプロファイルの選択」→「PowerShell」を選んでから、もう一度新しいターミナルを開きます（この資料のコマンドは `$HOME` などPowerShell前提のため、cmdでは動きません）。
4. **学校PCのみ**：Git にもプロキシを設定します（**自宅PCでは実行しないでください**）。1-2と同じ理由で、Git も学校のプロキシを知らないと外部と通信できません。ターミナルに以下を入力してEnterを押します。

   ```
   git config --global http.proxy http://proxy.example.invalid:8080
   ```

   > **⚠ このままコピーして貼らないでください。** `proxy.example.invalid:8080` と `8080` の部分は、1-2の手順1でメモした自分の学校の値に書き換えます。

   （読み下し：Gitに「外部と通信するときは、このプロキシを経由せよ」という設定を、この先ずっと使う設定として登録します。これをしないと、次のcloneや、8/18のGit演習でのpushが時間切れで失敗します。）

   > 間違えて自宅PCで実行してしまった場合は、`git config --global --unset http.proxy` を実行すると取り消せます。

5. リポジトリを置きたい場所（例：`ドキュメント` フォルダ）に移動します。ターミナルに以下を入力してEnterを押してください。

   ```
   cd $HOME\Documents
   ```

   （読み下し：`cd` は「このフォルダに移動する」という命令です。`$HOME` は自分のユーザーフォルダ（`C:\Users\自分の名前`）を表す省略記法なので、この1行で「自分のドキュメントフォルダに移動する」という意味になります。）

   > 別の場所に置きたい場合は `Documents` の部分を変えてください。いま自分がどこにいるか分からなくなったら `pwd` と入力すると現在地が表示されます。

6. 続けて、以下を入力してEnterを押します。

   ```
   git clone https://github.com/rei-okabayashi/classroom-temp-map.git
   ```

   （読み下し：GitHub上の `classroom-temp-map` リポジトリを、いまいる場所に丸ごと複製します。）

7. clone が終わったら、VSCode の `ファイル`（File）→ `フォルダーを開く`（Open Folder）で、clone してできた `classroom-temp-map` フォルダを開きます。

### 名前とメールを設定する

Gitに「誰の変更か」を教えるための設定です。これをしておかないと、初めてcommitしようとしたときに `Please tell me who you are` というエラーで止まってしまいます。

1. VSCode のターミナル（上の手順3で開いたもの）に、以下を1行ずつ入力してEnterを押します。

   ```
   git config --global user.name "ここに自分のGitHubユーザー名"
   git config --global user.email "ここに0-2でメモしたnoreplyアドレス"
   ```

   > **⚠ このままコピーして貼らないでください。** 引用符 `"` の中は、**自分の値に丸ごと書き換えます**。<br>
   > 例：ユーザー名が `taro-y` で、0-2でメモしたアドレスが `12345678+taro-y@users.noreply.github.com` なら、こう打ちます。
   >
   > ```
   > git config --global user.name "taro-y"
   > git config --global user.email "12345678+taro-y@users.noreply.github.com"
   > ```

   （読み下し：1行目でGitに「あなたの名前」を、2行目で「あなたのメールアドレス」を、この先ずっと使う設定として登録します。）

2. 以下を実行します。

   ```
   git config --global --list
   ```

   （読み下し：いま登録した設定の一覧を画面に表示します。）

   出力に `user.name=...` と `user.email=...` の2行が含まれていて、**`=` の右側が自分の値になっていればOK**です。
   `user.name=ここに自分のGitHubユーザー名` のように説明文がそのまま入っていたら、書き換えずにコピーしてしまっています。手順1をやり直してください（同じコマンドをもう一度実行すれば上書きされます）。

3. 最後に、Gitがコミットメッセージなどの入力を求めるときに開くエディタを、VSCodeにしておきます。以下を実行します。

   ```
   git config --global core.editor "code --wait"
   ```

   （読み下し：Gitが「メッセージを書いてください」とエディタを開く場面で、VSCodeを開くようにする、この先ずっと使う設定です。これをしないと、Git標準の Vim（ヴィム）という操作方法が特殊なエディタが開き、閉じ方を知らないと画面が固まったように見えて詰まります。もしVimが開いてしまったときは、`Esc` を押してから `:wq` と打って `Enter` で抜けられます。）

### リポジトリへの招待を承諾する（もう届いています）

このリポジトリは企画者が作成し、あとからメンバーを招待する形になっています。**招待はすでに送信済みです。**

1. 「invited you to collaborate」という件名のメールが、登録したメールアドレス宛に届いているはずです。
2. メール本文の「Accept invitation」ボタンを押します。
3. メールが見当たらない場合は、[https://github.com/notifications](https://github.com/notifications) を開いて確認してください。ここからでも承諾できます。
4. **承諾しないと push（自分の変更のアップロード）ができません。** ただし clone（複製）は承諾していなくてもできてしまうので、「cloneできたから大丈夫」とは判断せず、上の1〜3で承諾できているかを確かめてください。承諾したかどうか分からないときは、企画者にLINEで連絡してください。

### 初回pushでは認証画面が出る（予告）

8/18(火)のGit演習で初めて `git push` を実行すると、一度だけブラウザが自動で開き、GitHubへのサインインと許可（Authorize）を求められます。

1. 0章で作成したアカウントでログインします。
2. 内容を確認して許可（Authorize）します。
3. ブラウザからターミナルに戻ると、pushが完了しています。
4. 2回目以降のpushでは、この確認は出ません（自動で認証されます）。

---

## 6. node-template を開いて検証（コンパイル）する

ここでは、書いたプログラムを機械が実行できる形に変換し、文法ミスがないか確かめる「**コンパイル（検証）**」を行います。

1. **Arduino IDE** を開きます（VSCodeではなくArduino IDEを使います）。
2. `ファイル`（File）→ `開く`（Open...）で、clone した `classroom-temp-map` フォルダの中の `firmware/node-template/node-template.ino` を開きます。画面上部のタブに `node-template.ino` と `config.h` の2つが並んでいれば、正しく開けています。
3. 上部メニューの `ツール`（Tools）→ `ボード`（Board）→ `esp32` の中から「**ESP32 Dev Module**」を選択します。
4. 画面左上のチェックマークのアイコン（検証/コンパイル）をクリックします。
5. 下側の出力ウィンドウに赤いエラーが出ず、最後に「コンパイルが完了しました」（Done compiling）「スケッチが使用しているプログラム領域は...」のようなメッセージが出れば成功です（英語表示の場合は `Sketch uses ... bytes` の2行です）。

初回はコンパイルに数分かかることがあります（手順8のトラブルシュートも参照してください）。

### 集約担当のみ：gateway も検証する

1. 同じ手順で `firmware/gateway/gateway.ino` を開きます。
2. `ツール`（Tools）→ `ボード`（Board）→ `esp32` の中から「**M5Core**」を選択します（M5Stack Basic用のボード設定です）。
3. 検証（コンパイル）が通ることを確認します。手順4の M5Unified が入っていないと `M5Unified.h: No such file or directory` エラーになるので、その場合は手順4に戻ってください。

---

## 7. 実機への書き込みとシリアルモニタでの確認

ここでは、コンパイルしたプログラムをUSBケーブル経由でボードに転送する「**書き込み**」と、マイコンが出すメッセージをPCの画面で見るための窓である「**シリアルモニタ**」での確認を行います。

1. ESP32-DevKitC-32E をUSBケーブルでPCに接続します（手順3-1のドライバが入っている状態です）。
2. `ツール`（Tools）→ `シリアルポート`（Port）から、手順3-1でメモした `COMx` を選択します。

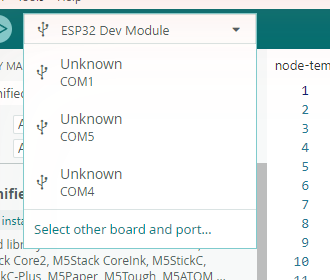
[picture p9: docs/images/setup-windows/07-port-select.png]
画面上部のボード名の右にある▼を開くと、COMポートの候補が一覧で出ます
   

   ※画面上部のボード名右の▼からも選べます。ボード名が「Unknown」と表示されても、手順3-1でメモしたCOM番号と一致していればそれを選んで問題ありません。
3. 画面左上の右矢印アイコン（マイコンボードに書き込む／Upload）をクリックします。
4. 出力ウィンドウに `Hard resetting via RTS pin...` や `Leaving...` のようなメッセージが出て、赤いエラーなく終われば書き込み成功です（うまくいかない場合は手順8の表を参照してください）。
5. `ツール`（Tools）→ `シリアルモニタ`（Serial Monitor）を開きます（虫眼鏡アイコン、または `Ctrl+Shift+M`）。
6. シリアルモニタ画面の右下にある通信速度のドロップダウンを **115200 baud** に合わせます。
7. 以下のような出力が表示されれば、書き込みと動作確認は完了です。

   ```
   === onmura node ===
   NODE_ID=n1  schema v1
   my MAC: xx:xx:xx:xx:xx:xx
   ```

   （読み下し：このノードが起動したことを知らせる見出し行は「onmura node」。`onmura` は「温度ムラ」をローマ字にした、このプロジェクトの略称です——画面の表示やファイル名など、日本語が使えない場所で使っています。ID は n1、データの形式は v1版。最後の行は、このボード固有のMACアドレス＝機器固有の番号です。MACアドレスは次の段落でくわしく説明します。）

   このあと30秒ごとに `send ok` または `send FAIL` の行が出ますが、この時点では **`send FAIL` や `add_peer failed` が出ても異常ではありません**。まだ `config.h` の `GATEWAY_MAC` を実際の集約M5StackのMACアドレス（**MACアドレス**＝機器1台ごとに工場出荷時から付いている固有の番号。機器の住所のようなものです）に書き換えていないためです（この書き換えは、各自が `firmware/nodes/n1` などにコピーして作業する段階で行います）。ここでは「シリアルにログが出続けている＝ボードが正常に動いている」ことだけ確認できればOKです。

### 集約担当のみ：M5Stackへの書き込み確認

1. M5Stack Basic をUSBケーブルで接続し、`ツール` → `シリアルポート` でM5Stack側のCOM番号を選びます（手順3-2でドライバ確認済みの前提です）。
2. ボードが「M5Core」になっていることを確認して、`firmware/gateway/gateway.ino` を書き込みます。

   **書き込みが `A fatal error occurred: Unable to verify flash chip connection` で失敗する場合**は、`ツール`（Tools）→ `Upload Speed`（書き込み速度）を **921600** に下げて、もう一度書き込んでください。2026-08-16の実機確認で、M5Coreの初期値である `1500000` は成功したり失敗したりと不安定でした。921600 で安定します。それでも失敗する場合は `115200` まで下げてください（書き込みに2〜3分かかりますが、まず失敗しません）。

3. シリアルモニタ（115200 baud）に以下が出て、M5Stackの画面下部にも同じMACが表示されればOKです。

   ```
   === onmura gateway ===
   MAC: xx:xx:xx:xx:xx:xx
   ```

   （読み下し：この集約役が起動したことを知らせる見出し行は「onmura gateway」。このM5Stack固有のMACアドレスは xx:xx:xx:xx:xx:xx。）

   **シリアルモニタに何も出てこないとき**は、シリアルモニタを開いたまま **M5Stack左側面のリセットボタン**を押してください。この2行は電源が入った直後に1回だけ出力されるので、書き込みのあとにシリアルモニタを開くと、その1回を見逃した状態になります（画面側にMACが出ていれば、ボード自体は正常に動いています）。

   この **MACアドレスが、各ノードの `config.h`（`GATEWAY_MAC`）に転記する値** になります。SDカード未挿入だと画面に `SD NG` と出ますが、環境構築の確認としてはこの時点では問題ありません。

---

## 8. トラブルシューティング

| 症状 | 主な原因 | 対処 |
|---|---|---|
| 起動してもロゴが脈動する画面のまま数分進まない | 学校PCなど、プロキシ経由でないと外部と通信できないネットワークで、IDEがプロキシを知らない | 1-2（プロキシ設定）を行ってください。1-2を設定済みでも直らない、またはその先のダウンロードが失敗する場合は、学校側の通信制限の可能性があるため企画者に連絡してください |
| デバイスマネージャーに COM ポートが出てこない | USBドライバが入っていない／ケーブルが通信非対応 | 手順3を再確認してください。ケーブルを別のものに替えてみてください（下の「充電専用ケーブル」も参照） |
| 書き込み（Upload）でエラーになる・失敗する | ボードが書き込みモードに入れていない | ボード上の **BOOT**（または **G0**）ボタンを見つけ、Upload実行と同時に長押しし、「Connecting...」の表示が出たらボタンを離してください。ESP32-DevKitC-32Eは通常は自動で書き込みモードに入りますが、うまくいかない基板では有効な回避策です |
| 書き込み中に応答がない／PCがケーブルを認識しない | 充電専用USBケーブルを使っている | データ通信線が入っていない安価なケーブルは書き込みに使えません。スマホのデータ転送用ケーブルなど、他の用途でファイル転送に使ったことがあるケーブルに替えてください |
| シリアルモニタに文字化けや無反応が出る／書き込み先を間違えている | ポート選択の間違い（別のCOM番号を選んでいる、他のUSB機器と混同） | `ツール` → `シリアルポート` の一覧を開き直し、ボードを一度抜き差ししてから増えたCOM番号を選び直してください。PCに複数のUSBデバイスを挿している場合は要注意です |
| 書き込みが `A fatal error occurred: Unable to verify flash chip connection` で失敗する | 書き込み速度（Upload Speed）が速すぎる | `ツール`（Tools）→ `Upload Speed` を **921600** に下げて、もう一度書き込んでください。それでも失敗する場合は `115200` まで下げてください（遅いですが確実です）。2026-08-16の実機確認で、M5Coreの初期値 `1500000` が不安定であることを確認しています |
| シリアルモニタに何も出てこない（ボードの画面は正常） | 起動時に1回だけ出る行を見逃している | `=== onmura gateway ===` や `=== onmura node ===` は電源が入った直後に1回だけ出ます。**シリアルモニタを開いたまま、ボードのリセットボタンを押して**ください。書き込みのあとにシリアルモニタを開くと、その1回を見逃した状態になります |
| ボードマネージャでesp32パッケージのインストール・コンパイルがとても遅い | 初回はダウンロード量が多い／PCのスペックやネット回線 | 初回のesp32パッケージインストールと初回コンパイルは特に時間がかかるのが普通です（数分〜数十分）。フリーズしたように見えても進捗バーやログが動いていれば待ってください。何十分も完全に無反応なら一度Arduino IDEを再起動して再試行してください |
| clone が `destination path '...' already exists and is not an empty directory` で失敗する | 置こうとした場所に同名フォルダがすでにある（ZIPでダウンロードした分や、前回の失敗の残りです） | 既存フォルダは消さずに、`git clone https://github.com/rei-okabayashi/classroom-temp-map.git classroom-temp-map2` のように**最後に別名を付けてclone**してください。どちらを残すかはあとで整理すればOKです |
| 学校PCで clone や push が時間切れ（timeout系のエラー）で失敗する | Git にプロキシが設定されていない | 5章の手順4（学校PCのみ：Gitにもプロキシを設定します）を実行してください |
| push で Authentication failed / Permission denied になる | 招待の未承諾、または別アカウントで認証している | 5章の「リポジトリへの招待を受け取る」の承諾を確認してください。ブラウザの認証画面では0章で作ったアカウントでログインしてください |
| `git status` などで `fatal: not a git repository` と出る | 開いているフォルダがcloneしたものではない（ZIPで展開したフォルダや別の場所。見た目が同じでも、履歴を持つ `.git` が無いとGitでは使えません） | 「ファイル」→「フォルダーを開く」で5章でcloneした `classroom-temp-map` を開き直してください。cloneがまだなら5章を実施してください |
| `git push` しても `Everything up-to-date` と出る／PRに変更が反映されない | 変更がまだcommitに入っていない（未保存、またはadd・commit漏れ。pushが送るのは「commit」だけです） | ①保存（Ctrl+S）→②`git status` で赤い表示を確認→③`git add <ファイル>`→④`git commit -m "..."`（出力の追加行数が0でないこと）→⑤`git push` の順でやり直してください |
| commit や pull の途中で黒い画面の見慣れないエディタが開き、操作できなくなった | Gitの既定エディタ（Vim）が開いて、コミットメッセージの入力を待っている | `Esc` を押してから `:wq` と打って `Enter` で、保存して抜けられます。5章「名前とメールを設定する」手順3の `git config --global core.editor "code --wait"` を実行しておくと、次からはVSCodeが開くようになります |

---

困ったときは、自己判断で強引に進めず、企画者に状況（どの手順で・どんなメッセージが出たか）を伝えて相談してください。

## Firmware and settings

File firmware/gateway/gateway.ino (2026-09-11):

// ================================================================
// 教室の温度ムラ「見える化」 集約側（M5Stack Basic・教壇常設）
//
// 役割: 各ノードからESP-NOWでJSONを受信し、
//   1) 画面にリアルタイム表示（校正オフセット適用後の値）
//   2) SDカードの /LOG.CSV に生値を1行追記（1行ごとにflush）
// データ契約v1（docs/data-contract.md）準拠。
//
// 時刻設定: PCとUSB接続し、シリアルモニタ(115200)から
//   TIME 2026-08-17 09:00:00
// と送ると時計が設定される。設定するまで画面に「時刻未設定」警告。
//
// ※これは企画者が用意した「動く骨組み」。ここから先が集約表示オーナーの領分:
//   画面レイアウトの改善・日本語表示・しきい値アラート(色)・校正値の反映・
//   時刻運用の改善・ミニグラフ など。
//
// 動作環境: M5Stack Basic / arduino-esp32 core 2.X系 / M5Unified
// ================================================================

#include <M5Unified.h>
#include <SD.h>
#include <WiFi.h>
#include <esp_now.h>
#include <esp_wifi.h>
#include <esp_mac.h>
#include <time.h>
#include <sys/time.h>
#include "config.h"

// ---- 受信キュー（コールバック内で重い処理をしないための受け渡し箱）----
#define QUEUE_SIZE 8
#define PKT_MAX    256   // ESP-NOWの上限250バイト+終端に収まるサイズ
#define HISTORY_SIZE 360 // Size of ring buffers which have temperature and humidity(Three hours' data)
#define Y_MAX 30  // Maximum value of the y-axis(y軸の最大値)
#define Y_MIN 20  // Minimum value of the y-axis(y軸の最小値)

static char queueBuf[QUEUE_SIZE][PKT_MAX];
static volatile int qHead = 0;  // コールバック(書く側)が進める
static volatile int qTail = 0;  // loop(読む側)が進める

// ---- ノードごとの最新状態（画面表示用）----
struct NodeState {
  bool     seen     = false;   // 一度でも受信したか
  uint32_t lastMs   = 0;       // 最終受信時刻(millis)
  uint32_t seq      = 0;
  float    t        = 0;       // 生値
  float    h        = 0;
  bool     sensorErr = false;
};
static NodeState nodes[NODE_COUNT];

// ---- For drawing graphes (グラフ表示用)
const int MAX_SCREENS = 1 + NODE_COUNT;
int screenMode = 0;
static float nodeTempRingBuffer[NODE_COUNT][HISTORY_SIZE] = {0.0f};
static float nodeHumidRingBuffer[NODE_COUNT][HISTORY_SIZE] = {0.0f};
static int write_index[NODE_COUNT] = {0};
static bool historyFull[NODE_COUNT] = {false};

static bool     clockSet  = false;  // TIMEコマンドで時刻設定済みか
static bool     sdOk      = false;
static uint32_t dropCount = 0;      // 解釈できなかった受信の数
static M5Canvas canvas(&M5.Display);
static bool     spriteOk = false;  // Basic(PSRAM無し)ではスプライト確保に失敗し得る
static String   myMac;

// ---- ESP-NOW受信コールバック（コピーだけして即返す）----
//void onRecv(const esp_now_recv_info_t *info, const uint8_t *data, int len) {  // for ESP32 core version 3.x after
void onRecv(const uint8_t *mac, const uint8_t *data, int len) {   // for ESP32 core version 2.x

  int next = (qHead + 1) % QUEUE_SIZE;
  if (next == qTail) return;                 // キューが満杯なら捨てる
  if (len <= 0 || len >= PKT_MAX) return;    // 長すぎるものも捨てる
  memcpy(queueBuf[qHead], data, len);
  queueBuf[qHead][len] = '\0';
  qHead = next;
}

// ---- 手組みJSONの読み取りヘルパー（契約のフィールドだけ拾う）----
static bool findU32(const char *json, const char *key, uint32_t &out) {
  char pat[24];
  snprintf(pat, sizeof(pat), "\"%s\":", key);
  const char *p = strstr(json, pat);
  if (!p) return false;
  out = strtoul(p + strlen(pat), nullptr, 10);
  return true;
}
static bool findFloat(const char *json, const char *key, float &out) {
  char pat[24];
  snprintf(pat, sizeof(pat), "\"%s\":", key);
  const char *p = strstr(json, pat);
  if (!p) return false;
  out = strtof(p + strlen(pat), nullptr);
  return true;
}
static bool findStr(const char *json, const char *key, char *out, size_t n) {
  char pat[24];
  snprintf(pat, sizeof(pat), "\"%s\":\"", key);
  const char *p = strstr(json, pat);
  if (!p) return false;
  p += strlen(pat);
  const char *q = strchr(p, '"');
  if (!q || (size_t)(q - p) >= n) return false;
  memcpy(out, p, q - p);
  out[q - p] = '\0';
  return true;
}

static int nodeIndex(const char *id) {
  for (int i = 0; i < NODE_COUNT; i++)
    if (strcmp(id, NODE_IDS[i]) == 0) return i;
  return -1;
}

// ---- 現在時刻を "2026-08-21 10:30:15" 形式で得る ----
static void nowString(char *out, size_t n) {
  time_t tt = time(nullptr);
  struct tm tmv;
  localtime_r(&tt, &tmv);
  strftime(out, n, "%Y-%m-%d %H:%M:%S", &tmv);
}

// ---- SDへ1行追記（openしてすぐclose＝1行ごとflushの契約）----
static void appendLog(const char *line) {
  if (!sdOk) return;
  File f = SD.open(LOG_PATH, FILE_APPEND);
  if (!f) { sdOk = false; return; }
  f.println(line);
  f.close();
}

// ---- 受信1件を処理: 状態更新 + CSV追記 ----
static void handlePacket(const char *json) {
  char id[8] = "";
  uint32_t seq = 0;
  if (!findStr(json, "id", id, sizeof(id)) || !findU32(json, "seq", seq)) {
    dropCount++;
    Serial.printf("drop (no id/seq): %s\n", json);
    return;
  }
  uint32_t v = 0;
  if (!findU32(json, "v", v) || v != SCHEMA_VERSION) {
    dropCount++;
    Serial.printf("drop (schema v%lu): %s\n", (unsigned long)v, json);
    return;
  }
  int idx = nodeIndex(id);
  if (idx < 0) {
    dropCount++;
    Serial.printf("drop (unknown id): %s\n", json);
    return;
  }

  char errbuf[16] = "";
  bool isErr = findStr(json, "err", errbuf, sizeof(errbuf));
  float t = 0, h = 0;
  if (!isErr && (!findFloat(json, "t", t) || !findFloat(json, "h", h))) {
    dropCount++;
    Serial.printf("drop (no t/h): %s\n", json);
    return;
  }

  // 状態更新（画面用）
  nodes[idx].seen      = true;
  nodes[idx].lastMs    = millis();
  nodes[idx].seq       = seq;
  nodes[idx].sensorErr = isErr;

  if (!isErr) { 
    nodes[idx].t = t; 
    nodes[idx].h = h; 
  }

  // If the data is valid, set the temperature and humidity,
  // if there is an error, set 0.0f
  float target_t = isErr ? 0.0f : (t + CAL_OFFSET_T[idx]);
  float target_h = isErr ? 0.0f : h;

  // Add t & h in ring buffer (リングバッファにt, hのデータを追加)
  nodeTempRingBuffer[idx][write_index[idx]] = target_t;
  nodeHumidRingBuffer[idx][write_index[idx]] = target_h;

  // Increment idx of the ring buffer. When it reaches the limit(HISTORY_SIZE 360),
  // reset it to 0 and set the historyFull flag
  write_index[idx]++;

  if (write_index[idx] >= HISTORY_SIZE) {
    write_index[idx] = 0;
    historyFull[idx] = true;
  }


  // CSV追記（契約: recv_time,clock,node_id,seq,temp_c,hum_pct,status）
  char ts[24];
  nowString(ts, sizeof(ts));
  char line[128];
  if (isErr) {
    snprintf(line, sizeof(line), "%s,%s,%s,%lu,,,sensor_err",
             ts, clockSet ? "set" : "unset", id, (unsigned long)seq);
  } else {
    snprintf(line, sizeof(line), "%s,%s,%s,%lu,%.1f,%.1f,ok",
             ts, clockSet ? "set" : "unset", id, (unsigned long)seq, t, h);
  }
  appendLog(line);
  Serial.println(line);
}

// ---- シリアルから "TIME 2026-08-17 09:00:00" を受け付ける ----
static void pollSerialTime() {
  static char buf[48];
  static int  pos = 0;
  while (Serial.available()) {
    char c = Serial.read();
    if (c == '\n' || c == '\r') {
      buf[pos] = '\0';
      pos = 0;
      int Y, M, D, hh, mm, ss;
      if (sscanf(buf, "TIME %d-%d-%d %d:%d:%d", &Y, &M, &D, &hh, &mm, &ss) == 6) {
        // 打ち間違い対策: 範囲外の値は時計を変更せず拒否する
        // （誤った値がclock=setとしてCSVに残ると、時刻未設定より発見が難しいため）
        if (Y < 2025 || Y > 2035 || M < 1 || M > 12 || D < 1 || D > 31 ||
            hh < 0 || hh > 23 || mm < 0 || mm > 59 || ss < 0 || ss > 59) {
          Serial.println("NG: 値が範囲外です。 usage: TIME 2026-08-17 09:00:00");
        } else {
          struct tm tmv = {};
          tmv.tm_year = Y - 1900; tmv.tm_mon = M - 1; tmv.tm_mday = D;
          tmv.tm_hour = hh; tmv.tm_min = mm; tmv.tm_sec = ss;
          struct timeval tv = { mktime(&tmv), 0 };
          settimeofday(&tv, nullptr);
          clockSet = true;
          char ts[24];
          nowString(ts, sizeof(ts));
          Serial.printf("clock set OK: %s\n", ts);  // 設定結果を読み返す（日付間違いに即気づけるように）
        }
      } else if (buf[0] != '\0') {
        Serial.println("usage: TIME 2026-08-17 09:00:00");
      }
    } else if (pos < (int)sizeof(buf) - 1) {
      buf[pos++] = c;
    }
  }
}


// ---- 一覧画面の列位置 ----
// 標準フォントは等幅(textSize 2 で1文字12px)。ラベルの文字数がノードごとに違っても
// 温湿度の列がずれないように、値の開始xはラベルの最大文字数(LABEL_CHARS)から固定で決める。
//   [n1 ][MADO-ATO][ 26.4C  55.2%]
//   x=8   x=44      x=148          (LABEL_CHARS=8 のとき。値13文字で右端304px)
#define CHAR_W2  12                                  // textSize 2 の1文字の幅[px]
#define ID_X     8
#define LABEL_X  (ID_X + CHAR_W2 * 3)                 // "n1 " の3文字分右
#define VALUE_X  (LABEL_X + CHAR_W2 * LABEL_CHARS + 8)

// ---- 画面描画（1秒ごと）----
// スプライト(メモリ上の下書き)が確保できればちらつきゼロで描く。
// Basic(PSRAM無し)で確保に失敗したときは画面へ直接描く(多少ちらつくが動く)。
static void drawScreen_list() {
  lgfx::LovyanGFX &g = spriteOk ? static_cast<lgfx::LovyanGFX &>(canvas)
                                : static_cast<lgfx::LovyanGFX &>(M5.Display);
  g.fillRect(0, 0, 320, 240, TFT_BLACK);
  g.setTextSize(1);

  // ヘッダ: 時刻（未設定なら警告）
  char ts[24];
  nowString(ts, sizeof(ts));
  if (clockSet) {
    g.setTextColor(TFT_WHITE);
    g.setCursor(8, 6);
    g.printf("%s", ts);
  } else {
    g.setTextColor(TFT_RED);
    g.setCursor(8, 6);
    g.printf("JIKOKU MISETTEI  (serial: TIME ...)");
  }
  g.drawFastHLine(0, 22, 320, TFT_DARKGREY);

  // ノード行
  for (int i = 0; i < NODE_COUNT; i++) {
    int y = 34 + i * 44;
    g.setTextSize(2);
    g.setTextColor(TFT_CYAN);
    g.setCursor(ID_X, y);
    g.printf("%s", NODE_IDS[i]);
    // 設置場所ラベル。"%-*.*s" = 左詰めで LABEL_CHARS 幅に揃え、超えた分は切り捨てる
    g.setTextColor(TFT_YELLOW);
    g.setCursor(LABEL_X, y);
    g.printf("%-*.*s", LABEL_CHARS, LABEL_CHARS, NODE_LABELS[i]);

    if (!nodes[i].seen) {
      g.setTextColor(TFT_DARKGREY);
      g.setCursor(VALUE_X, y);
      g.printf("---");
    } else if (millis() - nodes[i].lastMs > STALE_MS) {
      g.setTextColor(TFT_RED);
      g.setCursor(VALUE_X, y);
      g.printf("MUOUTOU %lus", (unsigned long)((millis() - nodes[i].lastMs) / 1000));
    } else if (nodes[i].sensorErr) {
      g.setTextColor(TFT_ORANGE);
      g.setCursor(VALUE_X, y);
      g.printf("SENSOR ERR");
    } else {
      // 表示にだけ校正オフセットを適用（CSVは生値のまま）
      g.setTextColor(TFT_WHITE);
      g.setCursor(VALUE_X, y);
      // g.printf("%5.1fC %5.1f%%", nodes[i].t + CAL_OFFSET_T[i], nodes[i].h);  // original
      g.printf("%5.1fC %5.1f%%", nodes[i].t + CAL_OFFSET_T[i], nodes[i].h); // more space between temp and humid
      g.setTextSize(1);
      g.setTextColor(TFT_DARKGREY);
      g.setCursor(VALUE_X + 2, y + 18);
      g.printf("seq=%lu  %lus ago", (unsigned long)nodes[i].seq,
               (unsigned long)((millis() - nodes[i].lastMs) / 1000));
      g.setTextSize(2);
    }
  }

  // フッタ: 自分のMAC（ノードのconfig.hに転記する値）とSD状態
  g.setTextSize(1);
  g.drawFastHLine(0, 214, 320, TFT_DARKGREY);
  g.setTextColor(TFT_GREENYELLOW);
  g.setCursor(8, 222);
  g.printf("MAC %s", myMac.c_str());
  g.setTextColor(sdOk ? TFT_GREEN : TFT_RED);
  g.setCursor(240, 222);
  g.printf(sdOk ? "SD OK" : "SD NG");
  if (dropCount > 0) {
    g.setTextColor(TFT_ORANGE);
    g.setCursor(180, 222);
    g.printf("drop:%lu", (unsigned long)dropCount);
  }

  if (spriteOk) canvas.pushSprite(0, 0);
}




// --- Draw Graph for each node / 各ノードのグラフ作成用
static void drawScreen_node(int idx) {
  lgfx::LovyanGFX &g = spriteOk ? static_cast<lgfx::LovyanGFX &>(canvas)
                                : static_cast<lgfx::LovyanGFX &>(M5.Display);

  // (0,0) 左上
  // |
  // +-- (10, 10) ➔ ここに「Graph: n1 MADO-ATO」の文字が描かれる（文字の高さは約16px）
  // |
  // +-- (40, 40) --------------------------- (310, 40)  ← 上の水平線
  // |            |                         |
  // |            |                         |
  // |            |  Graph Area             |
  // |            |  (Height: 160px)        |
  // |            |                         |
  // +-- (40,200) --------------------------- (310,200)  ← 下の水平線
  //              ↑                         ↑
  //           左の垂直線                右の垂直線                              
  
  // Draw background
  g.fillRect(0, 0, 320, 240, TFT_BLACK);

  // Title settings
  g.setTextSize(2);
  g.setTextColor(TFT_WHITE);
  g.setCursor(10, 10);
  
  g.printf("Graph: %s ", NODE_IDS[idx]);
  g.setTextColor(TFT_YELLOW);
  g.printf("%.*s", LABEL_CHARS, NODE_LABELS[idx]);   // 設置場所ラベル（一覧画面と同じ色）
  g.setTextColor(TFT_WHITE);                          // 以降の目盛り文字は白に戻す

  // Draw the outer frame(axes) of the graph
  // Draw Outer frame (top edge 40, bottom edge 200, left edge 10, right edge 310) 
  // g.drawRect(10, 40, 300, 160, TFT_DARKGREY); 
  g.drawFastHLine(40, 40,  270, TFT_DARKGREY); // 上の水平線 (X=40から横幅270)
  g.drawFastHLine(40, 200, 270, TFT_DARKGREY); // 下の水平線 (X=40から横幅270)
  g.drawFastVLine(40, 40,  160, TFT_DARKGREY); // 左の垂直線 (Y=40から縦幅160)
  g.drawFastVLine(310, 40, 160, TFT_DARKGREY); // 右の垂直線 (Y=40から縦幅160)
  // Draw center line
  g.drawFastVLine(175, 40, 160, TFT_DARKGREY);

  // Draw the tick marks (numbers) on the vertical axis
  // 縦軸のグラフのメモリを書く
  g.setTextSize(1);

  g.setCursor(12, 40-4);
  g.printf("%d C", (int)Y_MAX);

  g.setCursor(20, 120-4);
  g.printf("%d", (int)((Y_MAX + Y_MIN) / 2.0f));

  g.setCursor(20, 200-4);
  g.printf("%d", (int)Y_MIN);

  // Draw the tick marks (numbers) on the horizontal axis
  // 横軸のグラフのメモリを描く
  g.setCursor(40, 200 + 8);
  g.printf("0h");

  g.setCursor(160, 200 + 8);
  g.printf("1.5h");

  g.setCursor(290, 200 + 8);
  g.printf("3h");


  // --- Draw the line graph ---  
  int prev_x = 0, prev_y = 0;   // previous x, y
  // The flag to determine whether it is the first point(最初の点かどうかを判定する)
  bool is_first_point = true;
  // Determine the number of loop iterations in advance based on conditions
  int loop_count = historyFull[idx] ? HISTORY_SIZE : write_index[idx];

  int rb_idx = write_index[idx];

  for (int i = 0; i < loop_count; i++) {
    int data_idx = historyFull[idx] ? rb_idx : i;

     // x-coordinate (x座標)
    int x = 40 + (i * 270) / HISTORY_SIZE;

    // y-coordinate (y座標)
    float temp = nodeTempRingBuffer[idx][data_idx];
      
    if (temp == 0.0f) { // If the data is still empty (0.0), skip the rendering for this loop
      is_first_point = true;

      if (historyFull[idx]) {
        // next index (配列の次のindex)
        rb_idx = (rb_idx + 1) % HISTORY_SIZE; 
      }
      continue;
    }

    int y = 200 - (int)( (temp - Y_MIN) * 160.0f / (Y_MAX - Y_MIN) );

    // Force data falling outside the range to fit within the graph's boundaries (40–200)
    // 範囲外のデータを、グラフの枠内（40〜200）に強制的に閉じ込める
    y = constrain(y, 40, 200); 

    // plot and draw line
    g.drawPixel(x, y, TFT_WHITE);
    if (is_first_point) {
      is_first_point = false;
    } else {
      g.drawLine(prev_x, prev_y, x, y, TFT_WHITE);
    }

    prev_x = x;
    prev_y = y;

    if (historyFull[idx]) {
      // next index (配列の次のindex)
      rb_idx = (rb_idx + 1) % HISTORY_SIZE;
    }
  }

  if (spriteOk) {
    canvas.pushSprite(0, 0);
  }
}




void setup() {
  auto cfg = M5.config();
  M5.begin(cfg);
  Serial.begin(115200);

  // 8bitカラーにしてメモリを半分に(320x240で約77KB)。それでも確保できなければ直接描画
  canvas.setColorDepth(8);
  spriteOk = (canvas.createSprite(320, 240) != nullptr);
  if (!spriteOk) Serial.println("sprite確保失敗 -> 直接描画モード");

  // SDカード（M5Stack BasicはCS=GPIO4）
  sdOk = SD.begin(SD_CS_PIN);
  if (sdOk && !SD.exists(LOG_PATH)) {
    File f = SD.open(LOG_PATH, FILE_WRITE);
    if (f) {
      f.println("recv_time,clock,node_id,seq,temp_c,hum_pct,status");
      f.close();
    }
  }

  // ESP-NOW受信の準備
  WiFi.mode(WIFI_STA);
  WiFi.disconnect();
  esp_wifi_set_channel(WIFI_CHANNEL, WIFI_SECOND_CHAN_NONE);
  // MACはチップのeFuseから直接読む。
  // WiFi.macAddress() は arduino-esp32 3.3.x だと 00:00:00:00:00:00 を返すことがあり、
  // 2026-08-16のM5Stack Basic実機（core 3.3.11）で実際にゼロになった。
  // esp_read_mac(ESP_MAC_WIFI_STA) はWiFiの起動状態に関係なく実値を返す。
  {
    uint8_t mac[6];
    esp_read_mac(mac, ESP_MAC_WIFI_STA);
    char buf[18];
    snprintf(buf, sizeof(buf), "%02X:%02X:%02X:%02X:%02X:%02X",
             mac[0], mac[1], mac[2], mac[3], mac[4], mac[5]);
    myMac = String(buf);
  }
  Serial.printf("=== onmura gateway ===\nMAC: %s\n", myMac.c_str());
  Serial.println("時刻設定: TIME 2026-08-17 09:00:00 のように送信");

  if (esp_now_init() != ESP_OK) {
    Serial.println("esp_now_init failed. 5秒後に再起動します");
    delay(5000);
    ESP.restart();
  }
  esp_now_register_recv_cb(onRecv);

/*
  // ===============================================================
  // 【グラフィックテスト用ダミーデータ】
  //  本格的なテストのためには最低数分から3時間待たなければいけないため、
  //  ダミーデータを作成
  // ===============================================================
  for (int idx = 0; idx < NODE_COUNT; idx++) {
    for (int i = 0; i < 360; i++) {
      // 20度〜30度の間で、綺麗なサイン波（なだらかな波）を作るダミーデータ
      float dummy_temp = 25.0f + 5.0f * sin((float)i * 0.1f);
      
      // リングバッファに直接流し込む
      nodeTempRingBuffer[idx][i] = dummy_temp;
    }
    // 360件すべて埋まった状態（満杯フラグをtrueにする）
    write_index[idx] = 0;
    historyFull[idx] = true;
  }
  // ==========================================
*/
}



void loop() {
  M5.update();
  pollSerialTime();

  // キューにたまった受信を処理
  while (qTail != qHead) {
    handlePacket(queueBuf[qTail]);
    qTail = (qTail + 1) % QUEUE_SIZE;
  }

  // Change the screenMode value based on whether the button is pressed
  // ボタンが押されたかどうかでscreenMode値変更
  static uint32_t lastBtnMs = 0;

  if (M5.BtnA.wasPressed()) {
    uint32_t nowMs = millis();

    // 前回の判定から200m秒以上たっていない場合は無視(チャタリング防止)
    // Ignore if less than 200 milliseconds have elapsed since the previous determination (simple debouncing)
    if (nowMs - lastBtnMs >= 200) {
      lastBtnMs = nowMs;

      screenMode++;
      if (screenMode >= MAX_SCREENS) {
        screenMode = 0;
      }
    }

  }

  // 1秒ごとに画面更新
  static uint32_t lastDraw = 0;
  if (millis() - lastDraw >= 1000) {
    lastDraw = millis();
    
    if (screenMode == 0) {
      drawScreen_list();    // List view(一覧表示)
    } else {
      drawScreen_node(screenMode - 1);   // Graph view(グラフ表示)
    }
    
  }
  delay(10);
}

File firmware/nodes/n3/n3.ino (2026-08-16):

// ================================================================
// 教室の温度ムラ「見える化」 ノード側テンプレート
//
// 役割: SHT31で温湿度を測り、30秒ごとにJSONをESP-NOWで
//       集約M5Stackへ送る。データ契約v1（docs/data-contract.md）準拠。
//
// 各メンバーはこのフォルダを firmware/nodes/n1 などにコピーして
// 自分のノードとして育てる。書き換えてよいのは:
//   - config.h の NODE_ID と GATEWAY_MAC
//   - readSensor() の中身（別センサーに差し替える場合）
// 送信部・JSON部は「契約」なので変更しない（変えたいときは合意→v+1）。
//
// 動作環境: ESP32-DevKitC-32E / arduino-esp32 core 3.3系
// ================================================================

#include <WiFi.h>
#include <esp_now.h>
#include <esp_wifi.h>
#include <esp_mac.h>
#include <Wire.h>
#include "config.h"

static uint32_t seq = 0;              // 通番（起動から+1ずつ。欠落検出用）
static volatile bool sendDone = false; // 送信コールバックが来たか
static volatile bool sendOk   = false; // 送達確認の結果

// ---- 送信結果コールバック（ESP-NOWが送達確認を返してくる）----
void onSent(const wifi_tx_info_t *info, esp_now_send_status_t status) {
  sendOk   = (status == ESP_NOW_SEND_SUCCESS);
  sendDone = true;
}

// ---- SHT31 CRC-8チェック（多項式0x31, 初期値0xFF）----
static uint8_t sht31Crc(const uint8_t *data, int len) {
  uint8_t crc = 0xFF;
  for (int i = 0; i < len; i++) {
    crc ^= data[i];
    for (int b = 0; b < 8; b++) {
      crc = (crc & 0x80) ? (uint8_t)((crc << 1) ^ 0x31) : (uint8_t)(crc << 1);
    }
  }
  return crc;
}

// ---- センサー読み取り（ここが各自の担当部分）----
// 成功: tempC/humPct に値を入れて true を返す
// 失敗: false を返す（呼び出し側が err 送信に切り替える）
bool readSensor(float &tempC, float &humPct) {
  // 単発測定コマンド 0x2400（高リピータビリティ・クロックストレッチなし）
  Wire.beginTransmission(SHT31_ADDR);
  Wire.write(0x24);
  Wire.write(0x00);
  if (Wire.endTransmission() != 0) return false;

  delay(20);  // 測定待ち（データシート上は最大15ms）

  uint8_t buf[6];
  if (Wire.requestFrom((int)SHT31_ADDR, 6) != 6) return false;
  for (int i = 0; i < 6; i++) buf[i] = Wire.read();

  // buf: [温度H][温度L][CRC][湿度H][湿度L][CRC]
  if (sht31Crc(buf, 2) != buf[2]) return false;
  if (sht31Crc(buf + 3, 2) != buf[5]) return false;

  uint16_t rawT = ((uint16_t)buf[0] << 8) | buf[1];
  uint16_t rawH = ((uint16_t)buf[3] << 8) | buf[4];
  tempC  = -45.0f + 175.0f * rawT / 65535.0f;
  humPct = 100.0f * rawH / 65535.0f;
  return true;
}

// ---- 1回送信して送達確認を待つ。true=届いた ----
static bool sendOnce(const char *json) {
  sendDone = false;
  sendOk   = false;
  esp_err_t e = esp_now_send(GATEWAY_MAC, (const uint8_t *)json, strlen(json));
  if (e != ESP_OK) return false;
  uint32_t t0 = millis();
  while (!sendDone && millis() - t0 < 300) delay(1);  // 送達確認を最大300ms待つ
  return sendDone && sendOk;
}

// ---- 契約どおりの送信: 失敗したら1秒後に1回だけ再送 ----
static void sendWithRetry(const char *json) {
  if (sendOnce(json)) {
    Serial.printf("send ok : %s\n", json);
    return;
  }
  delay(1000);
  if (sendOnce(json)) {
    Serial.printf("send ok (retry): %s\n", json);
  } else {
    Serial.printf("send FAIL: %s\n", json);  // 諦めて次の周期に任せる（契約）
  }
}

void setup() {
  Serial.begin(115200);
  delay(300);
  Serial.println();
  Serial.println("=== onmura node ===");
  Serial.printf("NODE_ID=%s  schema v%d\n", NODE_ID, SCHEMA_VERSION);

  Wire.begin(PIN_SDA, PIN_SCL);

  // ESP-NOWはWiFi(STA)の上で動く。APには接続しない
  WiFi.mode(WIFI_STA);
  WiFi.disconnect();
  esp_wifi_set_channel(WIFI_CHANNEL, WIFI_SECOND_CHAN_NONE);
  // MACはチップのeFuseから直接読む（WiFi.macAddress() は arduino-esp32 3.3.x だと
  // 00:00:00:00:00:00 を返すことがあり、2026-08-16の実機で実際にゼロになった）。
  {
    uint8_t mac[6];
    esp_read_mac(mac, ESP_MAC_WIFI_STA);
    Serial.printf("my MAC: %02X:%02X:%02X:%02X:%02X:%02X\n",
                  mac[0], mac[1], mac[2], mac[3], mac[4], mac[5]);
  }

  // ありがちな設定忘れを起動時に警告（GATEWAY_MACが初期値のまま）
  bool macZero = true;
  for (int i = 0; i < 6; i++) if (GATEWAY_MAC[i] != 0) macZero = false;
  if (macZero) {
    Serial.println("!!! 警告: GATEWAY_MAC が未設定(全て0x00)です。");
    Serial.println("!!! M5Stackの画面に出るMACを config.h に転記してください。");
  }

  if (esp_now_init() != ESP_OK) {
    Serial.println("esp_now_init failed. 5秒後に再起動します");
    delay(5000);
    ESP.restart();
  }
  esp_now_register_send_cb(onSent);

  // 宛先（集約M5Stack）をピア登録
  esp_now_peer_info_t peer = {};
  memcpy(peer.peer_addr, GATEWAY_MAC, 6);
  peer.channel = WIFI_CHANNEL;
  peer.encrypt = false;  // 契約: 暗号化なし（環境データのみ・単純さ優先）
  if (esp_now_add_peer(&peer) != ESP_OK) {
    Serial.println("add_peer failed. config.h の GATEWAY_MAC を確認してください");
  }
}

void loop() {
  char json[128];
  float t, h;

  if (readSensor(t, h)) {
    // 正常時: {"v":1,"id":"n1","seq":123,"t":26.4,"h":55.2}
    snprintf(json, sizeof(json),
             "{\"v\":%d,\"id\":\"%s\",\"seq\":%lu,\"t\":%.1f,\"h\":%.1f}",
             SCHEMA_VERSION, NODE_ID, (unsigned long)seq, t, h);
  } else {
    // 読み取り失敗時: t/h を省略して err を送る（生存報告を兼ねる）
    snprintf(json, sizeof(json),
             "{\"v\":%d,\"id\":\"%s\",\"seq\":%lu,\"err\":\"sensor\"}",
             SCHEMA_VERSION, NODE_ID, (unsigned long)seq);
  }
  seq++;

  sendWithRetry(json);
  delay(SEND_INTERVAL_MS);  // 30秒待って次の測定へ
}

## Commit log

2026-08-01 初期コミット: テンプレファームウェア(コンパイル検証済)+データ契約v1+チーム運用ドキュメント一式
    - firmware/node-template: SHT31(0x45)読み取り+ESP-NOW送信(ch1/30秒/1回再送) — esp32 core 3.3.11でコンパイル検証済
    - firmware/gateway: M5Stack Basic 受信+画面表示+SD CSV記録(1行flush)+手動時刻設定 — 同上
    - docs: データ契約v1 / 環境構築(Win11) / Day 0台本 / Git入門 / 発表構成案 / バックログ / 初期タスク台帳
    - analysis: LOG.CSV→SQLite集計スクリプト(標準ライブラリのみ・サンプルデータで動作確認済)
    [LOG.CSV]
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2026-08-08 事前配布資料の整備＋メンバー4名確定の反映
    - setup-windows.md: 0章新設(GitHubアカウント作成・ユーザー名指針・メール非公開・2FA分岐・ユーザー名報告)、5章にgit config／招待受諾／初回push認証の予告を追加、ボードはDay 0配布の注記
    - docs/setup-discord.md・docs/roles.md 新設
    - README: Day 0記述の実態化・週次リズム小節・AI使いどころの目安・4名前提の役割表・担当欄はGitHubユーザー名
    - day0-agenda: タイムテーブル再編(役割の確認8分+機材配布5分)・事前宿題4点化・読み上げに週次リズムと24hルール
    - 8/3の3週間版改訂の未コミット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
2026-08-08 レイレビュー反映: M5Stackの譲渡対象外の理由を「企画者の個人所有物」に統一、筐体をメンバー担当時は正式役割へ格上げ(roles/README/day0/presentation/backlogの5ファイル一貫修正)
2026-08-08 机上チェックの反映: TIMEコマンド範囲チェック+分析の再送重複除去+実機チェックシート新設
    - gateway.ino: TIME範囲チェック(範囲外は時計不変)+設定時刻のエコーバック。core 3.3.11でコンパイル検証済(node69%/gateway86%)
    - analysis/log_to_sqlite.py: ACK消失再送による同一(node_id,seq)連続重複を除去。受け入れ3ケース(重複除外/seqリセット保持/無重複不変)合格
    - docs/first-boot-check.md新設: 初回動作確認A章/毎日チェックB章/SD安全回収C章/停電後D章/テスト送信注意E章
    - 校正オフセット文言を実装に合わせ統一(表示のみ・分析適用は未決定→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
2026-08-10 配布資料の文章を全面改訂（14ファイル）: ですます調に統一・専門用語に初出の説明を追加
    - 地の文・手順・表の説明文をですます調に統一（企画者指示 2026-08-11）
    - 専門用語は各文書内の初出で平易に説明（全文書共通の用語辞書で言い換えを統一）
    - コード例・コマンド・JSON/CSV例に読み下しを追加
    - 決定内容・数値・日付・URL・コード・【】欄は不変更（データ契約は変更履歴に1行追記のみ）
    - 内容是正2件: presentation-outlineの「表示・分析で校正適用」の断定を
    「表示のみ適用・分析は8/25までにチーム判断」に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
2026-08-11 setup-windows.md に画面スクリーンショット7枚を埋め込み（2章/4章/6章/7章）
    - Preferences・ボードマネージャesp32・M5Unified・node-template・コンパイル成功・ポート選択の実画面（赤枠注記つき）
    - 撮影環境が導入済みのため INSTALL が UPDATE 表示になる旨と、ポート一覧の Unknown 表示への注記を追加
    - 0章(GitHub画面)・3章(デバイスマネージャー)・Discord手順の画像は素材が撮れ次第追加予定
2026-08-11 setup-windows.md 0章にGitHub実画面5枚を埋め込み+UI変化に合わせ文言修正
    - ダッシュボード/プロフィールメニュー/メール非公開スイッチ/noreplyアドレス/2FA設定場所
    - 現行UIはチェックボックスでなくOn/Offスイッチのため「チェックを入れる」→「スイッチをOnにする」に修正
    - 撮影はダミーアカウントで実施、実メールアドレスはマスク済み
2026-08-11 新資料「放課後の進め方」(afterschool-plan.md)を追加+アンケート締切を8/15(土)23:59に統一
    - 放課後60分の基本の型(15:05終了/16:30強制下校)・月曜キックオフ/金曜デモの置き換え・週ごとの週末ライン
    - 8/27(木)追加講習日は放課後なしの前提で計画(8/26常設開始後なので記録は自動継続)
    - レビュー所見9件を反映(2週目火水の登校運用・時間内訳の算数・延長オプション・用語説明ほか)
    - 締切変更の波及: 役割かぶり調整は8/16(日)に実施へ統一(day0-agenda 3箇所)
    - READMEに構成ツリーとリンクを追記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
2026-08-11 新資料「タスクカード入門」(task-cards.md)を追加+放課後の時間割をレイ改訂版(16:10切り上げ)に整合
    - カード1枚の記入イメージ・どこで見るか・誰が作るか(初期26枚は企画者)・作り方7ステップ・ふだんの動かし方
    - レビュー所見6件を反映(自作カードはProjectsボードに自動で載らない注記・ボタン名Create主表記・出典明示ほか)
    - afterschool-plan前提節を短縮時間割(作業45分+確認10分・16:10切り上げ)に合わせて修正
    - README構成ツリーと週次リズムからリンク
2026-08-11 タスク管理を再設計: カンバン(Projects)は使わない・M1は事前宿題枠に再編（レイ決定 8/11）
    - tasks-initial: Issue登録はM2以降の21件のみ。M1の5件は事前宿題(LINE報告・Issue化しない・Day 0当日の作業でもない)と明記
    - task-cards: Projects関連の記述を「使わない」方針に書き換え。着手中の共有はDiscord2行が兼ねる
    - 理由: 4人・3週間の規模ではIssue一覧+マイルストーンで足り、覚える画面と手動メンテを増やさない
2026-08-11 Day 0を再設計: 学校PCへの環境導入をDay 0残り時間+8/18導入デーに配置、Git演習は8/18へ移動（レイ決定 8/11）
    - 背景: 放課後作業は学校PC(1人1アカウント・push認証OK)で行うため全員分の環境導入が必要
    - day0-agenda: タイムテーブル改(説明10分+軽い導入22分)、完了条件をDay 0/8/18に分割、
    招待Accept確認をDay 0完了条件に追加(未承諾は8/18のpushで初めて発覚するため)
    - 8/18が溢れた場合の持ち越し(8/21週末ラインまでに全員完了)とesp32時差DLを明記
    - tasks-initial: タスク27(学校PC導入)/28(Git演習完走)を追加、Issue登録対象は23件に
    - after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
2026-08-11 学校ルール反映: 私有USBメモリ・個人PC持ち込み禁止→インストーラは各自が学校回線でDL方式に変更
    - USB配布前提を撤去(day0-agenda事前準備/導入枠・setup-windows注記・tasks-initialタスク27)
    - 8/18の効率順: Arduino IDEのDLを先に仕掛け、待ち時間にGit演習を進める
    - ドライバが学校PCに入らない場合の代替を「書き込みは自宅PC→書き込み済みボードを持参」に修正(企画者PC持ち込み案を削除)
    - 下見タスクに「公式サイトからのDL可否(サイトブロック)」を追加
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2026-08-15 verifier指摘反映: 8/28と9/2を対等な判断日に修正、延長手続きにリハ日程の記述を追加、9/2見込みチェック行に削る順序docへの導線を追加
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2026-08-15 未経験者が実際に止まる箇所を実地検証して埋める(13件)
    8場面の実地シミュレーション(宿題/Day 0/導入デー/はんだ配線/M5Stack/分析/
    発表/整合)で「最初に手が止まる場所」を特定し、公開docs側を是正。
    環境構築(setup-windows):
    - cloneの前に打つ cd コマンドが無く、移動できずに止まる → 実コマンドを追加
    - git config の例をそのままコピペしても確認手順が「行があるか」しか見ず
    素通りする → 実例を併記し、確認基準を「=の右が自分の値か」に変更
    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
2026-08-15 集合日の曜日固定をやめ、アンケート実データに合わせて組み直す
    「1週目は月・火・金で確定」という言い切りを削除。実際には8/18(火)と
    8/19(水)にそれぞれ来られない人がいて、全員そろうのは月・木・金だった。
    - afterschool-plan: 曜日を固定しない方針に変更。1週目は全員そろう
    8/17・8/20・8/21を軸にし、8/18と8/19は来られる人だけで進めて
    あとで個別フォローする形に。「来られない日があるのは前提」と明記
    - day0-agenda / afterschool-plan: 学校PC導入デーを8/18と8/20の2段構えに
    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
2026-08-16 実機検証で判明した3件を修正: MACがゼロになるバグ/書き込み速度/シリアル無反応
    いずれも2026-08-16のM5Stack Basic実機(arduino-esp32 core 3.3.11)で確認。
    机上のコンパイル検証では検出できない類のもの。
    1. WiFi.macAddress() が 00:00:00:00:00:00 を返す(gateway/node-template両方)
    - 実測: シリアルも画面もゼロ。esptoolでチップから読むと実値が出る
    - esp_now_init は成功していたのでWiFiドライバ自体は起動済み
    - 対処: esp_read_mac(mac, ESP_MAC_WIFI_STA) でeFuseから直接読む
    - 影響: これがゼロだと tasks-initial #12(MACを出す作業)が完了できず、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
    [gateway.ino]
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2026-08-18 レビュー指摘を修正: 8章の表の行崩れ・テンプレのコメント復元・空の箇条書きを削除
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2026-08-23 firmware/nodes/ に n1〜n4 の置き場を作る（各自のコードを載せる先）
    READMEの構成図は firmware/nodes/n1〜n4 がある前提で書かれているのに、
    実体がどのブランチにも無かった。tasks-initial の T06〜T09 が
    「エクスプローラーでコピーする」で終わっていて、commit/push の手順が
    抜けていたため。
    中身は空にしてある（.gitkeep のみ）。各自が自分の nX.ino と config.h を
    足すだけで済み、既存ファイルと同じパスを取り合わないので衝突しない。
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2026-08-25 ノードケース（ESP32+SHT31）の3Dプリント設計たたき台を追加
    [node_case.scad, node_case_body.stl, node_case_lid.stl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]
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2026-08-31 コメントの指摘箇所修正と目盛り描画のし過ぎ修正
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2026-09-01 docs: 校正を実施しない判断(#24)をドキュメントに反映する
    Issue #24 を「実施しない」でcloseした判断を、ドキュメント側に反映する。
    根拠は実測: 誰もいない休日(空調停止・人の出入りなし)の5,741件で4台を突き合わせた
    ところ、台どうしの差は最大0.18℃だった。見たい差(授業時間の平均1.9℃・最大4.3℃)の
    10分の1以下なので、補正を入れても結論は変わらない。
    変更はドキュメントのみ。firmware/gateway/ は常設記録が終わるまで触らない
    (CAL_OFFSET_T は4台とも 0.0f のままで、実際の補正は掛かっていない)。
2026-09-01 Minor bug fix and change the max and min values of the y-axis as constants
    [gateway.ino]
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2026-09-01 docs: データシート引用の出典を版と箇所まで具体化する
    "factory calibrated, linearized and compensated" の引用を一次資料で確認した。
    出典は Sensirion 公式データシート SHT3x-DIS (2022年12月・Version 7) の
    図1の説明文で、原文は "The sensor signals for humidity and temperature are
    factory calibrated, linearized and compensated for temperature and supply
    voltage dependencies."。質疑で出典を聞かれても答えられるよう、版・箇所・URLを
    本文に書いた。
2026-09-01 Refactor graph logic and update temperature range to 18-34C based on review
    Changed the graph's displayed temperature range to 18°C–34°C based on review feedback. - Defined constants (Y_MAX, Y_MIN) for the Y-axis upper and lower limits to eliminate magic numbers. - Consolidated the redundant graph line-drawing loops (previously in if/else blocks) into a single shared process. - Implemented an is_first_point flag to fix a bug where missing data (0.0f) caused the graph to display abnormal diagonal lines. - Added logic in handlePacket to overwrite values with 0.0f, preventing a bug where historical data persisted after an error occurred following the 3-hour mark (buffer full)
    [gateway.ino]
2026-09-01 docs: README の役割表とノード設置場所を確定値に更新（#22）
    - ノードID n1〜n4 と担当者の対応を確定（各自が firmware/nodes/nX に
    push したコミットの author と一致）
    - 設置場所を「窓側/廊下側/教卓付近」の役割ベースで記入。席番号など
    教室が特定できる書き方は避ける方針を表の下に明記
    - 担当欄の表記を GitHub のユーザー名に統一（M27Kyara は表示名のため
    ログイン名の luvipmi72 に修正）
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2026-09-02 Update afterschool plan with schedule changes
    Removed unnecessary notes about calibration and updated the schedule for the week.
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2026-09-03 docs: 9/4 KPT進行台本・仕上げ週の段取り・1枚資料構成案を追加し、発表日を9/11に確定
    - docs/kpt-0904.md: 完成デモ→KPT30分→発表日までの決めごと、の進行台本
    - docs/final-week-plan.md: 9/4→9/11の日程表、9/9データ回収の段取り、リハ・当日の役割
    - docs/handout-0911.md: 発表当日に配るA4・1枚資料のレイアウトと作業の流れ
    - README / presentation-outline / afterschool-plan / tasks-initial: 発表日を「9月中旬」から 9/11（金）15:10 に更新
    Claude-Session: https://claude.ai/code/session_015kfR3X8cMG1y6jNmNG2dRR
2026-09-03 docs: 発表は普段の教室で授業終了5分後に開始する前提に修正
    - 会場移動・会場での通信テスト・機材の運搬とTIME再設定の記述を削除
    - 9/11当日は「準備」ではなく「確認」だけにするタイムラインへ差し替え
    - 9/9はデータ回収のみに簡略化、リハは通しと時間計測に絞る
    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
2026-09-03 修正しました!
2026-09-04 firmware: n3 のスケッチ名を n3.ino に修正する
    Arduino IDE はフォルダ名と同じ名前の .ino をメインスケッチとして扱うため、
    firmware/nodes/n3/ に n3.ino が無い状態ではスケッチとして開けなかった。
    firmware/nodes/README.md の「nX.ino … node-template.ino をコピーして名前を
    変えたもの」という自分たちの規約にも合っていなかった。
    変更はファイル名のみで、中身は1行も触っていない（n1.ino と同一内容、
    NODE_ID は config.h 側で "n3" になっていることを確認済み）。
    Claude-Session: https://claude.ai/code/se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
    [n3.ino]
2026-09-04 docs: 想定問答3にケースの影響を測っていない旨を追記する(#49)
    Issue #49 の並走測定は、専用の測定をやめて常設記録の休日データで
    判定する方式に変更した。個体差については PR #52 で 4台の差が最大
    0.18℃と実測済みだが、ケースの有無による絶対値の差は測っていない。
    発表でそこを聞かれたときに、測っていないものを測ったように答えない
    ための1行を想定問答3に足す。あわせて、全台に共通して乗るズレは
    地点どうしの差という今回の目的には影響しない旨を書いた。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
2026-09-10 docs: AI活用記録の修正
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2026-09-11 docs: READMEに実測結果を追加し、構成ツリーを現状に合わせる
    発表の手元資料にこのリポジトリのQRを載せるため、初めて見た人が
    「何を作って、何が分かったか」を先に読めるようにする。
    - 「わかったこと（実測の結果）」節を新設。8/24-8/28の実測から、
    最大差4.3℃・4地点差の中央値1.9℃・休日の地点別平均の幅0.18℃
    （＝補正なしで分析した根拠）を、発表スライドと配布A4と同じ数字で記載
    - 8/25のヒートマップ（配布A4に載せた白黒版）を docs/images/results/ に追加
    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
2026-09-11 docs: 制作期間の足場を整理する（docs 14本→5本・リポジトリ56%減）
    3週間の制作が終わったので、進め方の指示書として書いた文書と、
    役目の終わったスクリーンショットを整理する。設計・運用・分析の文書は残す。
    削除（すべて制作中の足場。内容は変更履歴に残る）:
    - docs/git-primer.md / task-cards.md / setup-discord.md … 汎用の入門資料
    - docs/tasks-initial.md … Issue #7〜#29 と二重管理。Issue側が正本
    - docs/day0-agenda.md / afterschool-plan.md / scope-cut-order.md … 日程と進行の台本
    - docs/backlog.md … 着手しなかった拡張案
    - docs/roles.md … REA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
    [gateway.ino]
2026-09-11 hardware: ノードケースを実際に設置した v3 に差し替える
    リポジトリに載っていたのは8/25のたたき台（body/lid/pod）で、実際に印刷して
    9/1から教室に設置したケースとは別物だった。最終版に入れ替える。
    - stl/ を6ファイルに差し替え: shell_n1〜n4（外殻＋センサークレードル・ノードID刻印）
    ＋ box（ESP32室）＋ lid（フタ）。全高58.5mm・設置面60.3×33.5mm
    - ソースを node_case.scad（OpenSCAD・v1）から node_case_v3.py（build123d）へ
    - hardware/case/README.md を v3 の構成で書き直し。3段積みの熱分離、必要な磁石、
    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
    [node_case.scad, node_case_body.stl, node_case_lid.stl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]
